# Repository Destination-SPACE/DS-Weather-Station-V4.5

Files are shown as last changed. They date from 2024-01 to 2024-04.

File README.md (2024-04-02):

<div align="center">
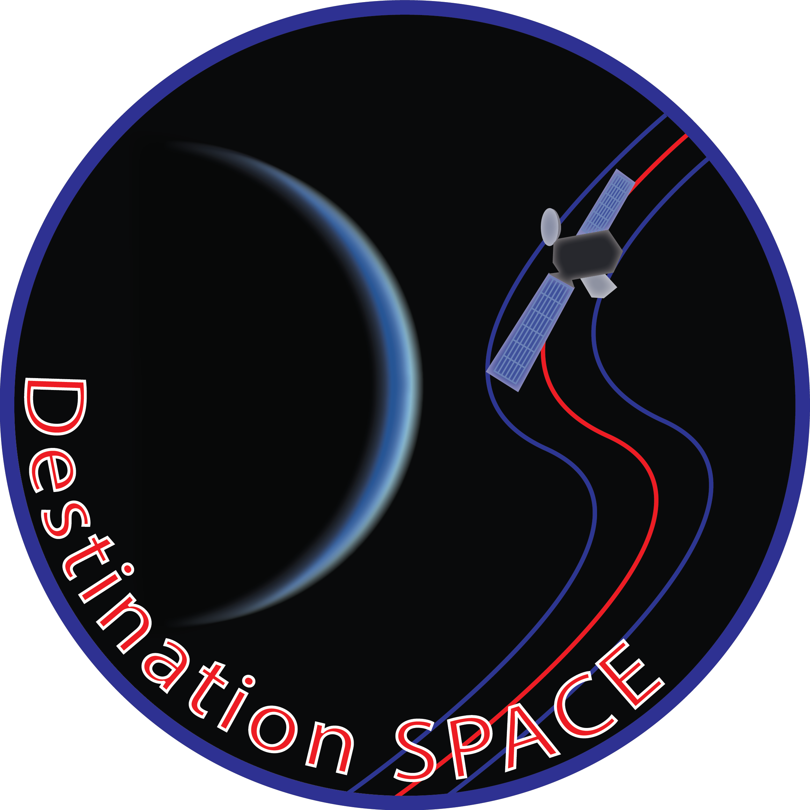
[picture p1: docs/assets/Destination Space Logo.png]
    
    <h1>Destination Weather Station v4.5.2</h1>
    <p>An Open Source Remote Sensing Platform for National Taiwan Normal University 🇹🇼</p>
</div>

## 🌟 About the Project
Destination Weather Station is the the latest version of remote sensing tools developed to teach students across Taiwan about climate science and remote sensing in partnership with National Taiwan Normal University.
## ⚙️ Hardware
All hardware files can be found [here](hardware/destinationWeatherStation_v4-5/)
## 💻 Software
All program files can be found [here](software)
## 🗂️ Documentation
Documentation for the weather station can be found [here](https://destination-space.gitlab.io/ds-weather-station-v4.5/)
## Licenses
Each of the above sections are individually licensed. Terms and conditions apply within their respective folders.

**Documentation - [Apache License 2.0](docs/LICENSE)** <br>
**Hardware - [CERN-OHL-P](hardware/destinationWeatherStation_v4-5//LICENSE)** <br>
**Software - [The MIT License](software/LICENSE)**

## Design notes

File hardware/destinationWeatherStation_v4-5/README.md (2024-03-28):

# Destination Weather Station v4.5 Hardware
KiCad files for Destination Weather Station v4.5

## KiCanvas
View schematic and PCB files with [KiCanvas](https://kicanvas.org/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)

## Directory
### [🧾 Bill of Materials](bom/bom.md)
### [📄 Datasheets](datasheets)
### [📐 Gerbers](gerber)
### [📰 Schematics](pdf)

Licensed under [CERN-OHL-P](LICENSE)

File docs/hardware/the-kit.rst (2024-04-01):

.. Copyright 2024 Destination SPACE Inc.
   Licensed under the Apache License, Version 2.0 (the "License");
   you may not use this file except in compliance with the License.
   You may obtain a copy of the License at

      http://www.apache.org/licenses/LICENSE-2.0

   Unless required by applicable law or agreed to in writing, software
   distributed under the License is distributed on an "AS IS" BASIS,
   WITHOUT WARRANTIES OR CONDITIONS OF ANY KIND, either express or implied.
   See the License for the specific language governing permissions and
   limitations under the License.

.. _the-kit:

What is in the Kit?
===================

.. Insert kit image here

Kit Contents
------------
- Destination Weather Station v4.5.2
- Seeeduino XIAO RP2040 microcontroller w/ headers
- 128x64px OLED display w/ headers
- SPDT power switch
- AAA battery case
- 8GB micro-SD card
- USB-A to USB-C cable
- USB microSD card adapter

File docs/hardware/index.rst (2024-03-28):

.. Copyright 2024 Destination SPACE Inc.
   Licensed under the Apache License, Version 2.0 (the "License");
   you may not use this file except in compliance with the License.
   You may obtain a copy of the License at

      http://www.apache.org/licenses/LICENSE-2.0

   Unless required by applicable law or agreed to in writing, software
   distributed under the License is distributed on an "AS IS" BASIS,
   WITHOUT WARRANTIES OR CONDITIONS OF ANY KIND, either express or implied.
   See the License for the specific language governing permissions and
   limitations under the License.

.. _hardware:

Overview of Hardware
====================

The Destination Weather Station was designed in `KiCad <https://www.kicad.org/>`_ and assembled by hand. the weather station includes several features that improve user experience. These are:

.. toctree::
   :maxdepth: 1

   power
   storage
   hid

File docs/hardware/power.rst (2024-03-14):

.. Copyright 2024 Destination SPACE Inc.
   Licensed under the Apache License, Version 2.0 (the "License");
   you may not use this file except in compliance with the License.
   You may obtain a copy of the License at

      http://www.apache.org/licenses/LICENSE-2.0

   Unless required by applicable law or agreed to in writing, software
   distributed under the License is distributed on an "AS IS" BASIS,
   WITHOUT WARRANTIES OR CONDITIONS OF ANY KIND, either express or implied.
   See the License for the specific language governing permissions and
   limitations under the License.

.. _power:

Power
=====

The power subsystem of the weather station was designed with reverse voltage protection in mind. Typically, if a battery is connected to a circuit backwards, it will not work, or worse, fry the entire system. This is why reverse current protection is often added to circuits to prevent such user error. This allows the user to not have to worry about the polarity of their LiPo battery. On the Destination Weather Station v4.5 we have taken this one step further, by not only having reverse voltage/polarity protection, but also correcting this polarity. This works using the same principal as an `AC rectifier <https://en.wikipedia.org/wiki/Rectifier>`_ circuit. This DC rectifier consists of two `N-Channel MOSFETs <https://en.wikipedia.org/wiki/NMOS_logic>`_ and two `P-Channel MOSFETs <https://en.wikipedia.org/wiki/PMOS_logic>`_. These MOSFETs combine to essentially create a rectifier circuit, which will only allow the correct polarity to pass through the FETs. A schematic of this circuit can be found below.

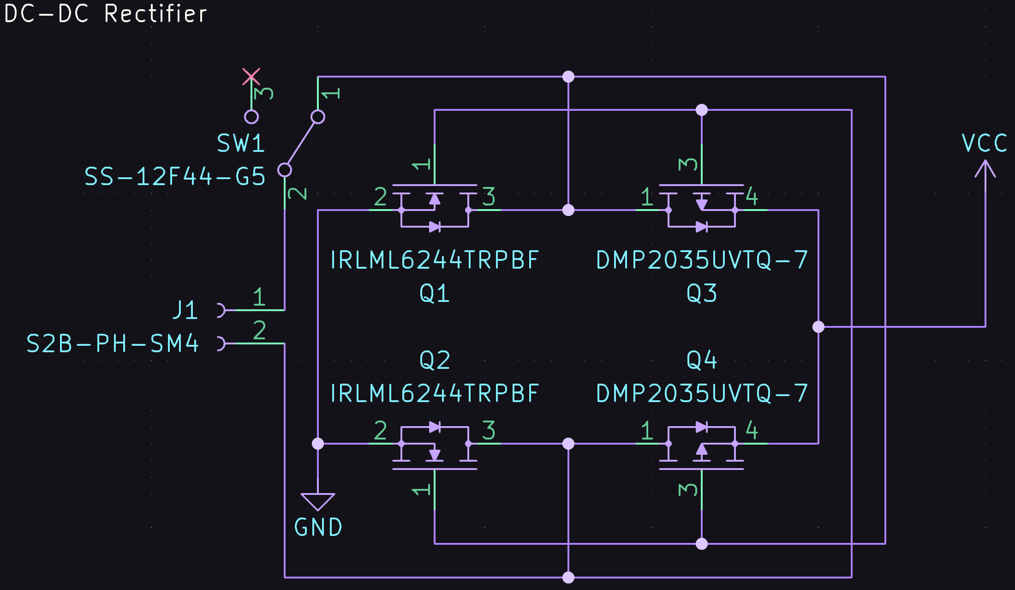
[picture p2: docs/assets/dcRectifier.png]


**Note:** There is no over-current protection, so make sure to not exceed 5V in.

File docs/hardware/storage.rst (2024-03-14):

.. Copyright 2024 Destination SPACE Inc.
   Licensed under the Apache License, Version 2.0 (the "License");
   you may not use this file except in compliance with the License.
   You may obtain a copy of the License at

      http://www.apache.org/licenses/LICENSE-2.0

   Unless required by applicable law or agreed to in writing, software
   distributed under the License is distributed on an "AS IS" BASIS,
   WITHOUT WARRANTIES OR CONDITIONS OF ANY KIND, either express or implied.
   See the License for the specific language governing permissions and
   limitations under the License.

.. _storage:

Storage
=======

The storage on the Destination Weather station is simply a microSD card slot to store recorded sensor data for further evalulation. There is also chip-detect functionality which allows the code to know if a card has been inserted or not.

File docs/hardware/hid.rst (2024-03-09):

.. Copyright 2024 Destination SPACE Inc.
   Licensed under the Apache License, Version 2.0 (the "License");
   you may not use this file except in compliance with the License.
   You may obtain a copy of the License at

      http://www.apache.org/licenses/LICENSE-2.0

   Unless required by applicable law or agreed to in writing, software
   distributed under the License is distributed on an "AS IS" BASIS,
   WITHOUT WARRANTIES OR CONDITIONS OF ANY KIND, either express or implied.
   See the License for the specific language governing permissions and
   limitations under the License.

.. _hid:

Human Interface Devices
=======================

On the Destination Weather Station there are 4 buttons, which are the primary way to interact with the device. These buttons are each labeled with arrows ↑, ↓, ←, →. These buttons are used to scroll through the menus and to switch between the different data displays.

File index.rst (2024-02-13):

.. Copyright 2024 Destination SPACE Inc.
   Licensed under the Apache License, Version 2.0 (the "License");
   you may not use this file except in compliance with the License.
   You may obtain a copy of the License at

      http://www.apache.org/licenses/LICENSE-2.0

   Unless required by applicable law or agreed to in writing, software
   distributed under the License is distributed on an "AS IS" BASIS,
   WITHOUT WARRANTIES OR CONDITIONS OF ANY KIND, either express or implied.
   See the License for the specific language governing permissions and
   limitations under the License.

Destination Weather Station v4.5
================================

An Open Source Remote Sensing Platform for National Taiwan Normal University

Contents
--------

.. toctree::
   :maxdepth: 1

   about-the-project

.. toctree::
   :caption: Getting Started
   :maxdepth: 1

   hardware/the-kit
   hardware/assembly
   tutorials/index

.. toctree::
   :caption: Configuration
   :maxdepth: 1

   software/install-arduino-ide
   software/weather-station-configuration

.. toctree::
   :caption: Experiments

.. toctree::
   :caption: Sensors
   :maxdepth: 1

   sensors/index
   sensors/calibration
   sensors/bme280
   sensors/ens160
   sensors/scd40
   sensors/veml7700
   sensors/ltr390

.. toctree::
   :caption: Hardware
   :maxdepth: 1

   hardware/index
   faq/troubleshooting
   hardware/power
   hardware/storage
   hardware/hid
   hardware/pcb/index
   hardware/pcb/manufacturing

.. toctree::
   :caption: Software
   :maxdepth: 1

   software/index
   software/blink
   software/basics
   software/i2c-scanner
   software/sensor-test
   software/demo

.. toctree::
   :caption: Miscellaneous
   :maxdepth: 1

   FAQ <faq/index>

.. * :ref:`genindex`
.. * :ref:`modindex`
.. * :ref:`search`

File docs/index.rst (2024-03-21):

.. Copyright 2024 Destination SPACE Inc.
   Licensed under the Apache License, Version 2.0 (the "License");
   you may not use this file except in compliance with the License.
   You may obtain a copy of the License at

      http://www.apache.org/licenses/LICENSE-2.0

   Unless required by applicable law or agreed to in writing, software
   distributed under the License is distributed on an "AS IS" BASIS,
   WITHOUT WARRANTIES OR CONDITIONS OF ANY KIND, either express or implied.
   See the License for the specific language governing permissions and
   limitations under the License.

Destination Weather Station v4.5
================================

An Open Source Remote Sensing Platform for National Taiwan Normal University

Contents
--------



.. toctree::
   :caption: Getting Started
   :maxdepth: 2

   hardware/the-kit
   hardware/assembly

.. toctree::
   :caption: Configuration
   :maxdepth: 2

   software/install-arduino-ide

.. toctree::
   :caption: Sensors
   :maxdepth: 2

   sensors/index
   sensors/bme280
   sensors/ens160
   sensors/ltr390
   sensors/scd40
   sensors/veml7700

.. toctree::
   :caption: Hardware
   :maxdepth: 2

   hardware/index
   faq/troubleshooting
   hardware/power
   hardware/storage
   hardware/hid

.. toctree::
   :caption: Software
   :maxdepth: 2

   software/index
   software/blink
   software/sensor-test
   software/demo
   software/full-code

.. toctree::
   :caption: Activities
   :maxdepth: 2

   activities/index
   activities/tempurature
   activities/humidity
   activities/CO2
   activities/VOCs
   activities/ALS
   activities/UVA

.. toctree::
   :caption: Miscellaneous
   :maxdepth: 2

   FAQ <faq/index>

.. * :ref:`genindex`
.. * :ref:`modindex`
.. * :ref:`search`

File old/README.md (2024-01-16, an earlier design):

# Destination Weather Station v4.5 Documentation
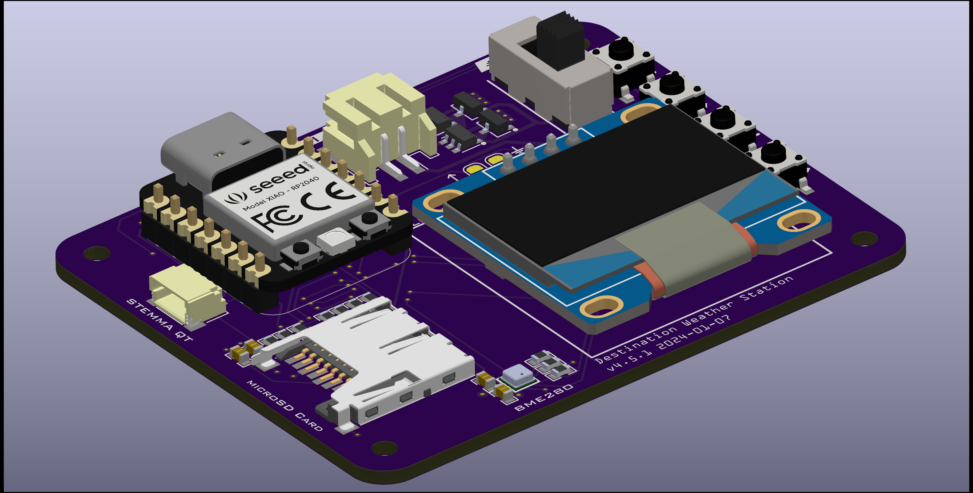
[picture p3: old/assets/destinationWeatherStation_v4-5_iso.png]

## Directory
[//]: # (Directory Links)
<div>
<h3>
<details>
  <summary><a href="#-getting-started">🚀 Getting Started</a></summary>
  <ul>
    <li><a href="#-whats-included">📝 What's Included</a></li>
    <details>
        <summary><a href=#-getting-started>🔧 Soldering</a></summary>
        <ul>
        <li><a href="#step-1">Step 1</a></li>
        <li><a href="#step-2">Step 2</a></li>
        <li><a href="#step-3">Step 3</a></li>
        <li><a href="#step-4">Step 4</a></li>
        <li><a href="#step-5">Step 5</a></li>
        </ul>
    </details>
    <li><a href="#final-assembly">Final Assembly</a></li>
  </ul>
</details>
</h3>

<h3>
<details>
  <summary><a href="uploading-code.md">💻 Uploading Code</a></summary>
  <ul>
    <li><a href="uploading-code.md#💾-downloading-arduino-ide">💾 Downloading Arduino IDE</a></li>
    <details>
        <summary><a href="uploading-code.md#💻-configuring-arduino-ide">💻 Configuring Arduino IDE</a></summary>
        <ul>
        <li><a href="uploading-code.md#📥-installing-board-manager">📥 Installing Board Manager</a></li>
        <li><a href="uploading-code.md#📥-installing-code-libraries">📥 Installing Code Libraries</a></li>
        </ul>
    </details>
    <li><a href="uploading-code.md#👾-example-programs">👾 Example Programs</a></li>
  </ul>
</details>
</h3>

<h3>
<details>
  <summary><a href="collecting-data.md">🗃️ Collecting Data</a></summary>
  <ul>
    <li><a href="">Domain 1</a></li>
    <details>
        <summary><a href=>Sub-Domain List 1</a></summary>
        <ul>
        <li><a href="">Sub-Domain 1</a></li>
        <li><a href="">Sub-Domain 2</a></li>
        <li><a href="">Sub-Domain 3</a></li>
        <li><a href="">Sub-Domain 4</a></li>
        <li><a href="">Sub-Domain 5</a></li>
        </ul>
    </details>
    <li><a href="">Domain 2</a></li>
  </ul>
</details>
</h3>

<h3>
<details>
  <summary><a href="collecting-data.md">🧪 Experiments</a></summary>
  <ul>
    <li><a href="">Domain 1</a></li>
    <details>
        <summary><a href=>Sub-Domain List 1</a></summary>
        <ul>
        <li><a href="">Sub-Domain 1</a></li>
        <li><a href="">Sub-Domain 2</a></li>
        <li><a href="">Sub-Domain 3</a></li>
        <li><a href="">Sub-Domain 4</a></li>
        <li><a href="">Sub-Domain 5</a></li>
        </ul>
    </details>
    <li><a href="">Domain 2</a></li>
  </ul>
</details>
</h3>
</div>

## 🚀 Getting Started

### 📝 What's Included
- 1x Destination Weather Station v4.5
- 1x Seeeduino XIAO RP2040 microcontroller with headers
- 1x 128x64px OLED display with headers
- 1x SPDT slide switch
- 1x 4.5V AAA battery case
- 3x AAA batteries
- 1x USB A to USB C cable
- 1x 8GB microSD card
- 1x microSD to USB A adapter

### 🔧 Soldering

#### Step 1:
- Take 2 1x7 male header pins and insert the long side of the pins into the board
- Carefully flip the board upside-down, without letting the headers fall out
- Place the tip of the soldering iron at the corner between the 1st pin and the gold pad, allowing it to heat up the board for 2-3 seconds
- Feed solder onto the pad with your other hand. The solder should melt and flow around the pad and pin.
- Remove the soldering iron after 2-3 more seconds
- Repeat with the 7th pin, then the other pins in the middle
- Repeat with the other 1x7 header

#### Step 2:
- Following the same steps above, solder the 1x4 header to the board

#### Step 3:
- Place the Seeeduino XIAO RP2040 on the 1x7 headers, with the USB C port and buttons facing up
- Following the same soldering techniques, solder all 14 pins on the XIAO

#### Step 4:
- Place the OLED display on the 1x4 header with the screen facing up
- Solder the first pin using the same technique used for the other pins
- Before soldering the other pins, hold the screen with one hand, and heat up the soldered pad
- Adjust the screen so it is flat with the weather station board
- Solder the 4th pin, then the 2 middle pins

#### Step 5:
- Insert the SPDT switch into the weather station board
- Carefully flip the board upside-down, without letting the button fall out
- Using the same technique as before, solder the 2 outside pins of the switch, then solder the 3 middle pins

### Final Assembly
- Insert the AAA batteries into the battery case
- Insert the microSD card into the weather station
- Write your name on the back of the weather station in the white box provided

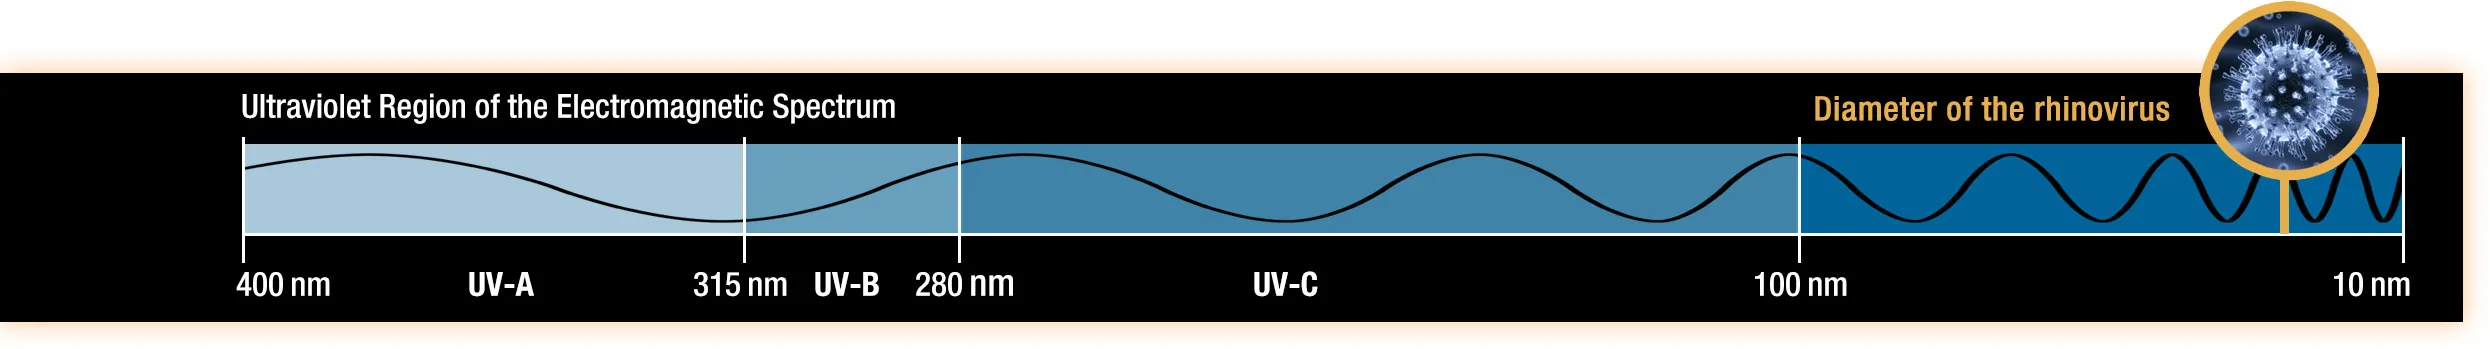
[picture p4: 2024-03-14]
docs/assets/ultravioletSpectrum.webp

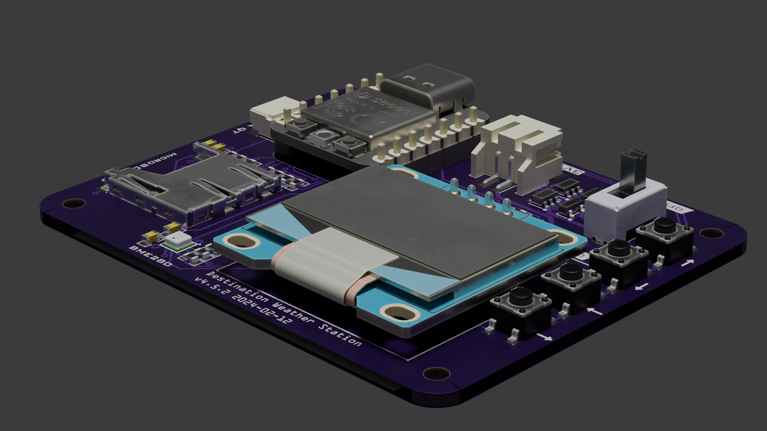
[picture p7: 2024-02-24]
hardware/destinationWeatherStation_v4-5/blender/firstRender.png

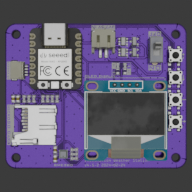
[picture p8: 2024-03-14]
hardware/destinationWeatherStation_v4-5/blender/thumbnail2.png

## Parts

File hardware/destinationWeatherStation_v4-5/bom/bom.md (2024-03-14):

# Bill of Materials
*Note: Some parts may be replaced with suitable alternatives

| Item | Qty | Reference | Value | Datasheet | Manufacturer | Manufacturer Part Number | Package |
|-----:|----:|:---:|:-----:|:---|:---|:---|---:|
| 1 | 1 | C1 | 10uF | [AVX-CX5R-KGM](../datasheets/AVX-CX5R-KGM-MLCC.pdf) | KYOCERA AVX | KGM15CR51A106MT | 0603 |
| 2 | 3 | C2, C3, C4 | 0.1uF | [AVX-CX5R-KGM](../datasheets/AVX-CX5R-KGM-MLCC.pdf) | KYOCERA AVX | KGM15AR51H104KT | 0603 | 
| 3 | 10 | R1, R2, R3, R4, R5, R6, R7, R8, R9, R10 | 10K | [D/CRCW e3](../datasheets/Vishay-Dale-DCRCWe3.pdf) | Vishay Dale | CRCW060310K0JNEB | 0603 |
| 3 | 2 | R11, R12 | 0R | [D/CRCW e3](../datasheets/Vishay-Dale-DCRCWe3.pdf) | Vishay Dale | CRCW06030000Z0EA | 0603 |
| 4 | 2 | Q1, Q2 | IRLML6244TRPBF | [IRLML6244TRPBF](../datasheets//Infineon-IRLML6244.pdf) | Infineon Technologies | IRLML6244TRPBF | SOT-23 |
| 5 | 2 | Q3, Q4 | DMP2035UVTQ | [DMP2035UVTQ](../datasheets/Diodes-Incorporated-DMP2035UVTQ.pdf) | Diodes Incorporated | DMP2035UVTQ-7 | TSOT26 |
| 6 | 1 | U1 | XIAO RP2040 | [XIAO RP2040](https://wiki.seeedstudio.com/XIAO-RP2040/) | Seeed Studio | XIAO RP2040 | N/A |
| 7 | 1 | U2 | BME280 | [BME280](../datasheets/BST-BME280.pdf) | Bosch Sensortec | BME280 | 2.5x2.5mm LGA |
| 8 | 1 | U3 | OLED | [HS96L03W2C03](../datasheets/HS-HS96L03W2C03.pdf) | SHENZHEN HANSHENG INDUSTRAIL CO. | HS96L03W2C03 | N/A |
| 9 | 1 | SW1 | SS-12F44-G5 | [SS-12F44-G5](../datasheets/SS-12D07-VG_GA_PA.pdf) | C&K | SS-12D07-VG 4 NS GA PA | N/A |
| 10 | 4 | SW2, SW3, SW4, SW5 | PTS647SM38SMTR2LFS | [PTS647SM38SMTR2LFS](../datasheets/C&K-PTS647.pdf) | C&K | PTS 647 SM38 SMTR2 LFS | N/A |
| 11 | 1 | J1 | S2B-PH-SM4 | [JST-PH](../datasheets/JST-PH-Connectors.pdf) | JST Sales America Inc. | S2B-PH-SM4-TB(LF)(SN) | N/A |
| 12 | 1 | J2 | MEM2061 | [MEM2061](../datasheets//GCT-MEM2061.pdf) | GCT | MEM2061-01-188-00-A | N/A |
| 13 | 1 | J3 | SM04B-SRSS | [JST-SH](../datasheets/JST-SH-Connectors.pdf) | JST Sales America Inc. | SM04B-SRSS-TB | N/A |

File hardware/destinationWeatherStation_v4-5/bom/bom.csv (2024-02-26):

Item | Qty | Reference(s) | Value | Manufacturer | mpn | populate
1 | 1 | C1 | 10uF | KYOCERA AVX | KGM15CR51A106MT | 1
2 | 3 | C2, C3, C4 | 100nF | KYOCERA AVX | KGM15AR51H104KT | 1
3 | 1 | J1 | S2B-PH-SM4 | JST Sales America Inc. | S2B-PH-SM4-TB(LF)(SN) | 1
4 | 1 | J2 | MEM2061 | GCT | MEM2061-01-188-00-A | 1
5 | 1 | J3 | STEMMA_QT | JST Sales America Inc. | SM04B-SRSS-TB | 1
6 | 2 | Q1, Q2 | IRLML6244TRPBF | Infineon Technologies | IRLML6244TRPBF | 1
7 | 1 | Q3 | DMP2035UVTQ-7 | Diodes Incorporated | DMP2035UVTQ-7 | 1
8 | 1 | Q4 | DMP2035UVTQ-7 | Diodes Incorporated | DMP2035UVTQ-7 | 1
9 | 10 | R1, R2, R3, R4, R5, R6, R7, R8, R9, R10 | 10K | Vishay Dale | CRCW060310K0JNEB | 1
10 | 2 | R11, R12 | 0R | Vishay Dale | CRCW06030000Z0EA | 1
11 | 1 | SW1 | SS-12F44-G5 | C&K | SS-12D07-VG 4 NS GA PA | 0
12 | 4 | SW2, SW3, SW4, SW5 | PTS647SM38SMTR2LFS | C&K | PTS 647 SM38 SMTR2 LFS | 1
13 | 1 | U1 | XIAO RP2040 | Seeed Studio | XIAO RP2040 | 0
14 | 1 | U2 | BME280 | Bosch Sensortec | BME280 | 1
15 | 1 | U3 | HS96L03W2C03 | SHENZHEN HANSHENG INDUSTRAIL CO. | HS96L03W2C03 | 0

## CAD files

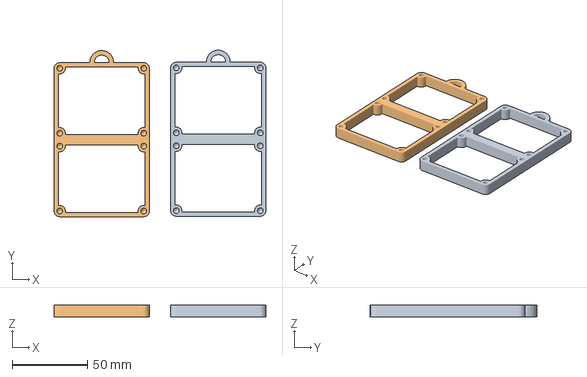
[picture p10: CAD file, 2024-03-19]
hardware/balloonMount/balloonMount_x2.3mf
141.0 x 110.8 x 8.00 mm
balloonMount_x2.stl x 2

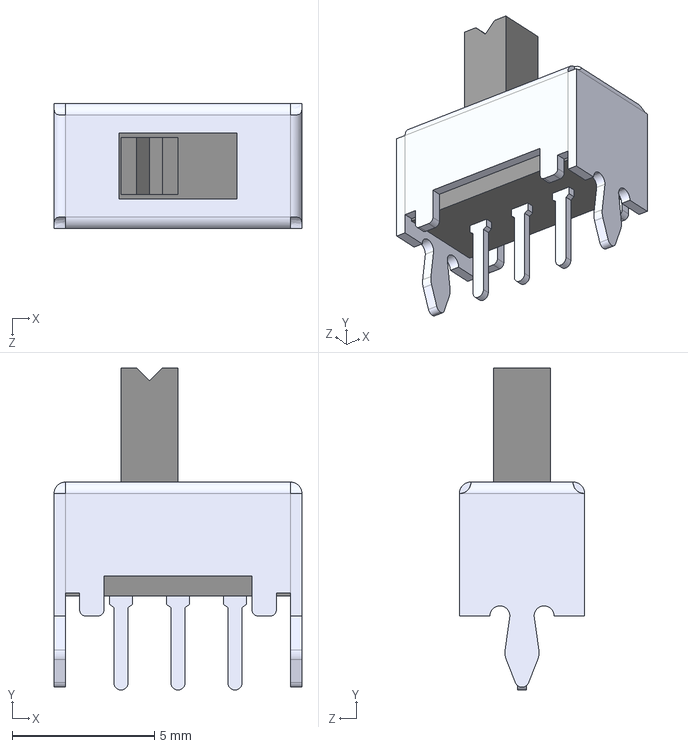
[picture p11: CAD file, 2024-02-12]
hardware/destinationWeatherStation_v4-5/3d_models/SS12D07VG4.STEP
8.70 x 11.3 x 4.40 mm

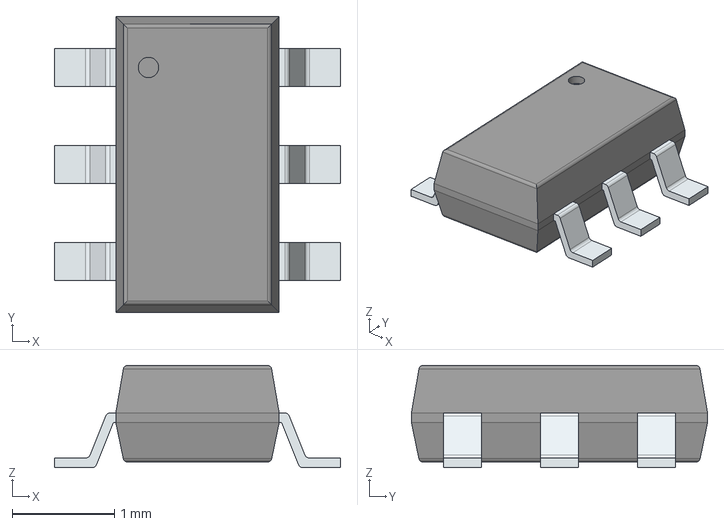
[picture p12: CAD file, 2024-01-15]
hardware/destinationWeatherStation_v4-5/3d_models/DMP2035UVTQ-7.stp
2.80 x 2.90 x 1.00 mm
PinsArrayLR

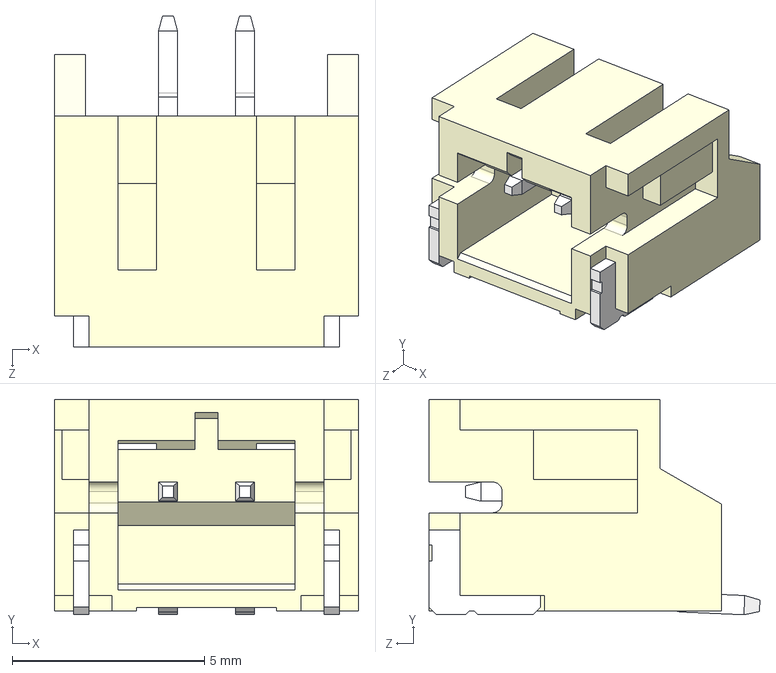
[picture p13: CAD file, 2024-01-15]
hardware/destinationWeatherStation_v4-5/3d_models/S2B-PH-SM4-TB(LF)(SN).STEP
7.90 x 5.60 x 8.60 mm

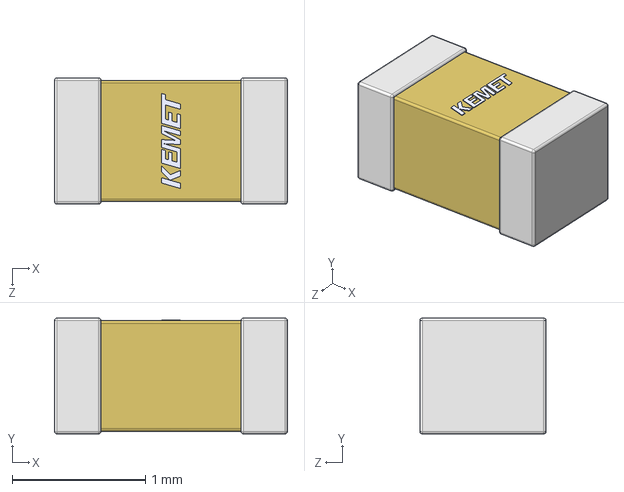
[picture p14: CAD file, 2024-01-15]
hardware/destinationWeatherStation_v4-5/3d_models/C0603C104K5RACTU.stp
1.75 x 0.87 x 0.95 mm

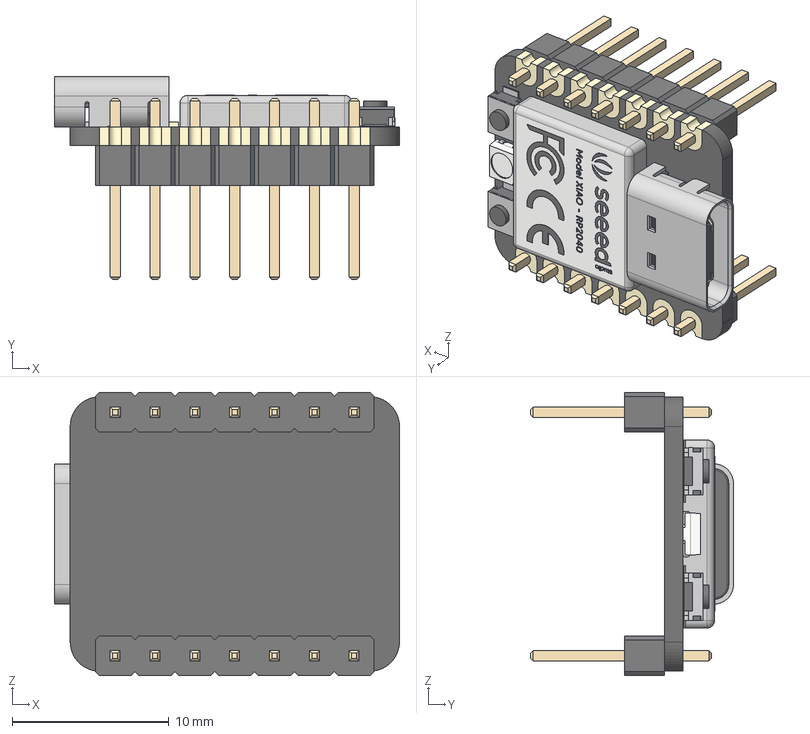
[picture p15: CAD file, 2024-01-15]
hardware/destinationWeatherStation_v4-5/3d_models/xiaoRP2040_with_pins.stp
22.0 x 12.9 x 18.1 mm
type-c v2
smd_button v3
DOUT
DIN
VSS
VDD
smd_button v3(Mirror)
PinHeader_1x07_P254mm_Vertical x 2

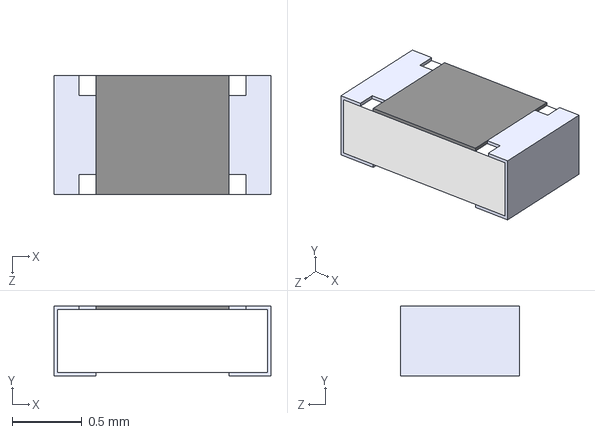
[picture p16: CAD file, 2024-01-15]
hardware/destinationWeatherStation_v4-5/3d_models/CRCW0603.STEP
1.55 x 0.5 x 0.85 mm

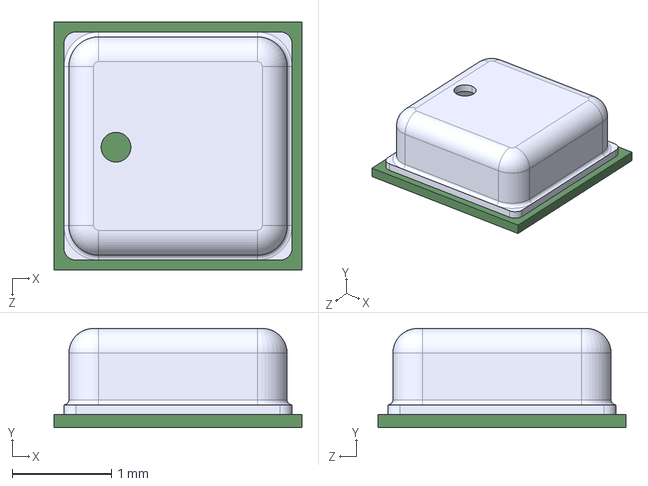
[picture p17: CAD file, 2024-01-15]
hardware/destinationWeatherStation_v4-5/3d_models/BME280.STEP
2.50 x 1.00 x 2.50 mm

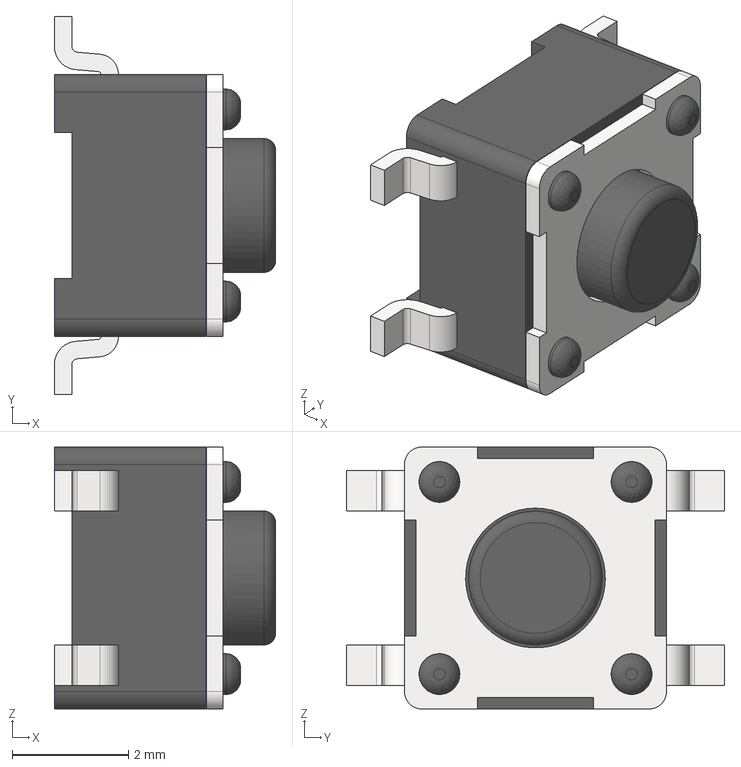
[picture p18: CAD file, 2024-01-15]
hardware/destinationWeatherStation_v4-5/3d_models/PTS647SM38SMTR2LFS.stp
3.80 x 6.50 x 4.50 mm

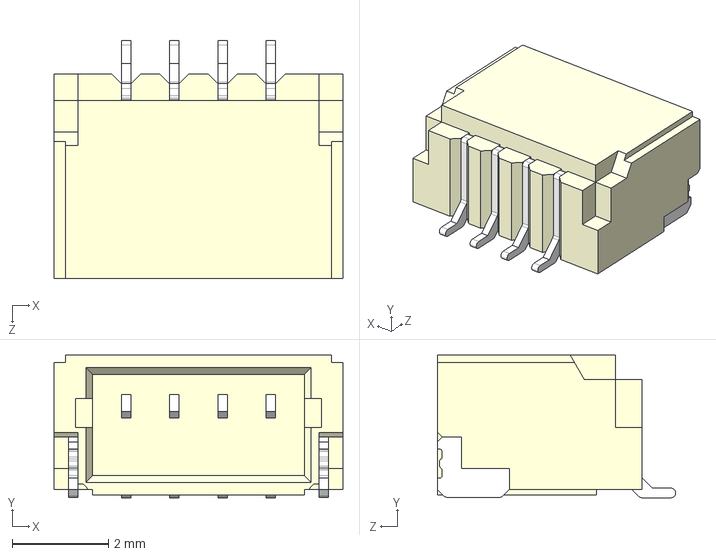
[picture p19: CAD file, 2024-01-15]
hardware/destinationWeatherStation_v4-5/3d_models/SM04B-SRSS-TB(LF)(SN).STEP
6.00 x 2.96 x 4.95 mm

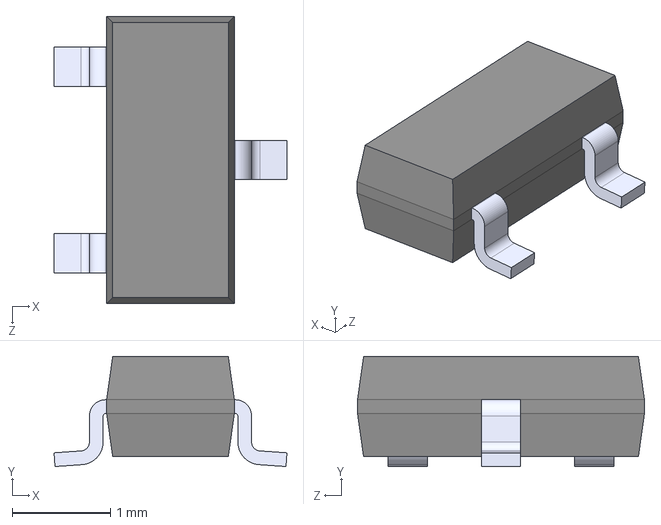
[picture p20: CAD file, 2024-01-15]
hardware/destinationWeatherStation_v4-5/3d_models/IRLML6244TRPBF.STEP
2.37 x 1.12 x 2.92 mm

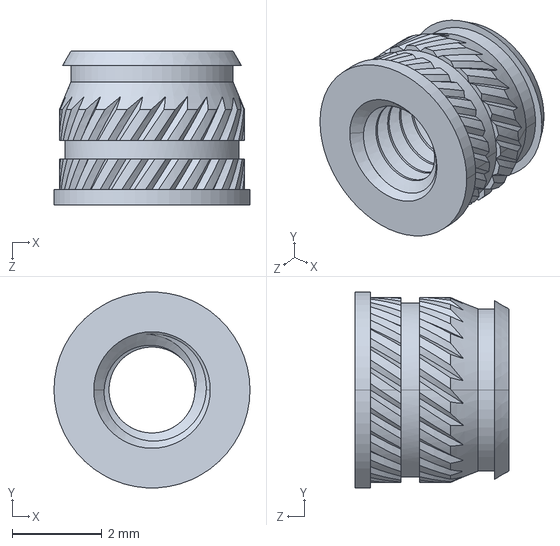
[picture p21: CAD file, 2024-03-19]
hardware/balloonMount/94180A321_Tapered Heat-Set Inserts for Plastic.STEP
4.37 x 4.36 x 3.43 mm

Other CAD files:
hardware/balloonMount/94180A321_Tapered Heat-Set Inserts for Plastic/94180A321_Tapered Heat-Set Inserts for Plastic.ipt
hardware/balloonMount/OldVersions/balloonMount.0002.iam
hardware/balloonMount/balloonMount.iam
hardware/balloonMount/balloonMount_x2.ipt
hardware/balloonMount/balloonMount_x2.stl
hardware/balloonMount/destination-automation-v4.5-test-jig/destination-automation-v4.5-test-jig.ipt
hardware/balloonMount/destinationAutomation_r4/OldVersions/destinationAutomation_r4.0001.ipt
hardware/balloonMount/destinationAutomation_r4/destinationAutomation_r4.ipt
hardware/balloonMount/destinationWeatherStation_v4-5/ASSEMBLY.ipt
hardware/balloonMount/destinationWeatherStation_v4-5/Assembly1.ipt
hardware/balloonMount/destinationWeatherStation_v4-5/BME280.iam
hardware/balloonMount/destinationWeatherStation_v4-5/BME280.ipt
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

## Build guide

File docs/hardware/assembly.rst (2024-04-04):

.. Copyright 2024 Destination SPACE Inc.
   Licensed under the Apache License, Version 2.0 (the "License");
   you may not use this file except in compliance with the License.
   You may obtain a copy of the License at

      http://www.apache.org/licenses/LICENSE-2.0

   Unless required by applicable law or agreed to in writing, software
   distributed under the License is distributed on an "AS IS" BASIS,
   WITHOUT WARRANTIES OR CONDITIONS OF ANY KIND, either express or implied.
   See the License for the specific language governing permissions and
   limitations under the License.

.. _assembly:

Destination Weather Station v4.5 Assembly
=========================================

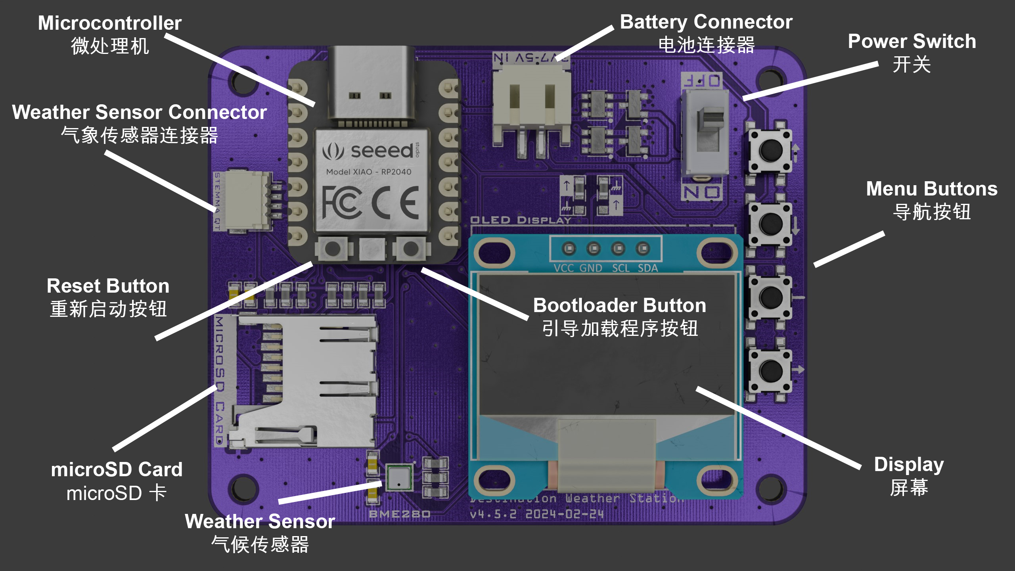
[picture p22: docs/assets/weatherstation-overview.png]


The Destination Weather Station v4.5 is preassembled with the majority of the circuit components.

Before using the weather station, you will need to :ref:`solder<soldering>` the :ref:`XIAO RP2040 microcontroller<xiao-RP2040>`, :ref:`OLED display<oled-display>`, and :ref:`power switch<switch>`. Follow the instructions below to solder your weather station. You can then :ref:`connect the batteries<batteries>` and insert the microSD card.

Soldering
---------

.. _soldering:

To solder the weather station, follow the instructions below. Tools required to complete these steps are:

* Soldering iron
* Solder wire

Power Switch
~~~~~~~~~~~~

.. _switch:

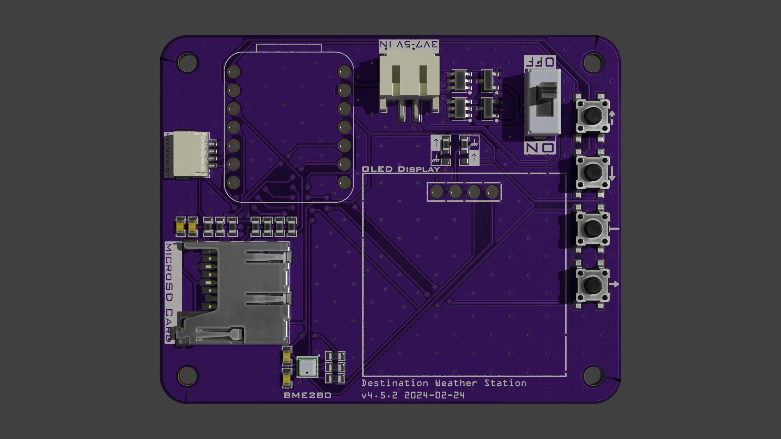
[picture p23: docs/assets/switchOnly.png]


To solder the power switch to the weather station, insert it into the front side of the board. Flip the board over and solder the pins, starting with the two outer ones.

XIAO RP2040
~~~~~~~~~~~

.. _xiao-RP2040:

To solder the XIAO RP2040 to the weather station, begin by inserting the long side of the 1x7 header pins into the weather station board as shown below.

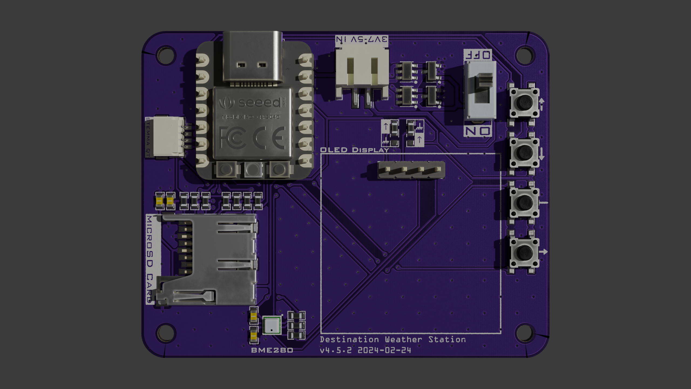
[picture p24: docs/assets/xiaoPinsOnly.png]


Next, flip the weather station over and solder all 14 pins to the weather station.

Finally, flip the weather station back over and solder the XIAO to the short side of the header pins. After you are done, it should look like the image below.

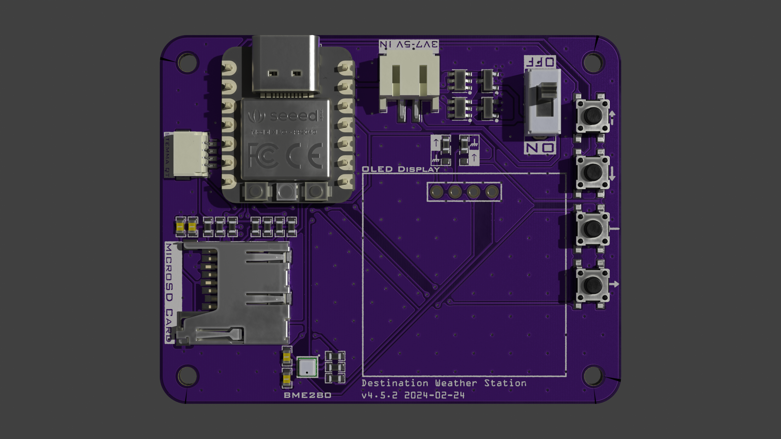
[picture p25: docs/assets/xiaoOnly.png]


OLED Display
~~~~~~~~~~~~

.. _oled-display:

To solder the OLED display to the weather station, you will follow similar procedures to the steps above to solder the XIAO.

Begin by inserting the long side of the 1x4 header into the weather station board as shown below.

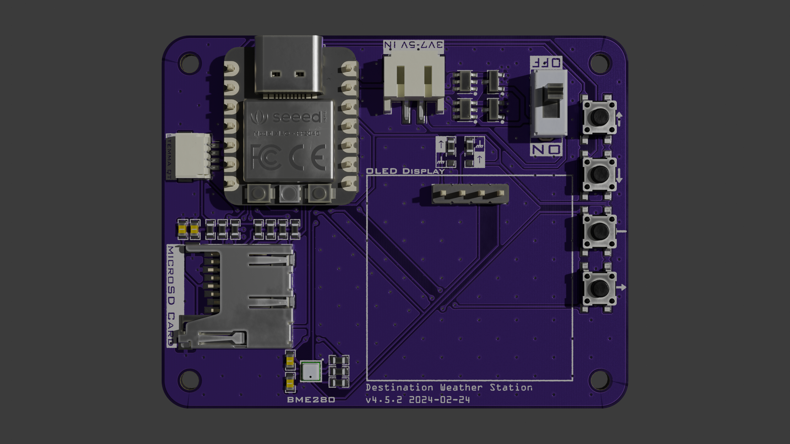
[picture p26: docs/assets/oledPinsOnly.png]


Next, flip the board over and solder the pins to the back.

Similarly, flip the board back over and solder the display to the front.



Final Assembly
--------------


Batteries
~~~~~~~~~

.. _batteries:

Insert three (3) AAA batteries into the battery pack. Connect the JST-PH connector to the matching connector on the weather station.

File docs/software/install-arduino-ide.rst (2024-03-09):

.. Copyright 2024 Destination SPACE Inc.
   Licensed under the Apache License, Version 2.0 (the "License");
   you may not use this file except in compliance with the License.
   You may obtain a copy of the License at

      http://www.apache.org/licenses/LICENSE-2.0

   Unless required by applicable law or agreed to in writing, software
   distributed under the License is distributed on an "AS IS" BASIS,
   WITHOUT WARRANTIES OR CONDITIONS OF ANY KIND, either express or implied.
   See the License for the specific language governing permissions and
   limitations under the License.

.. _install-arduino-ide:

Installing Arduino IDE
======================

To program the Destination Weather Station, you will need to download and install Arduino IDE.

Download
~~~~~~~~

To begin, navigate to https://www.arduino.cc/en/software.

Click ``Windows Win 10 and newer, 64 bits`` under the most recent version of IDE. This may be different than the screenshot below

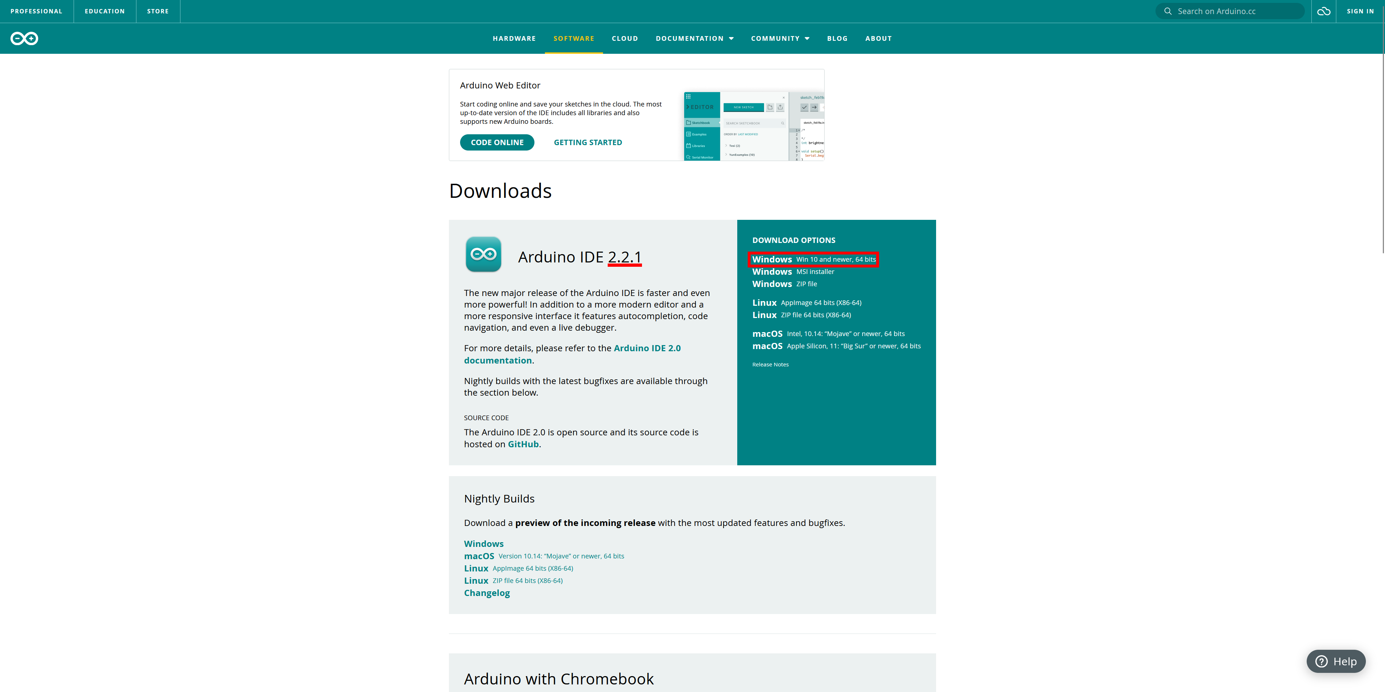
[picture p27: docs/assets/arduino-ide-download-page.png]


When the page loads, click next

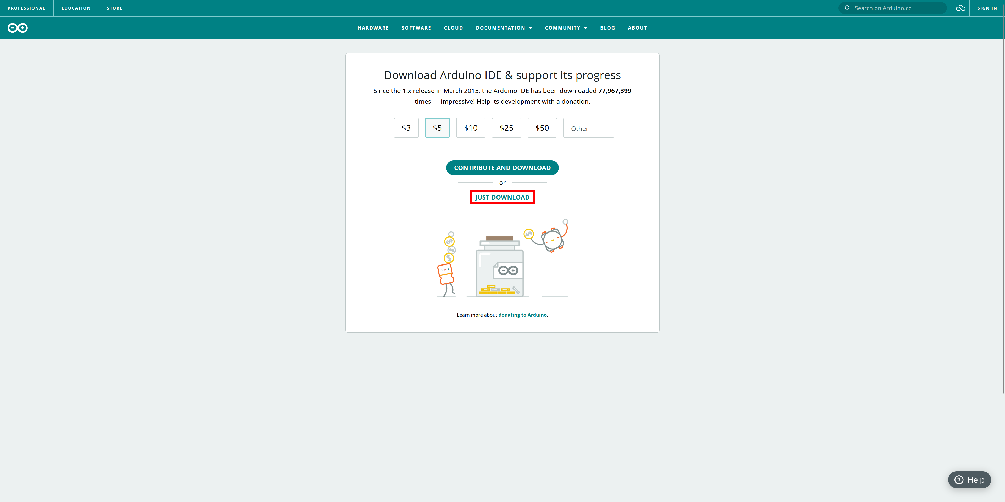
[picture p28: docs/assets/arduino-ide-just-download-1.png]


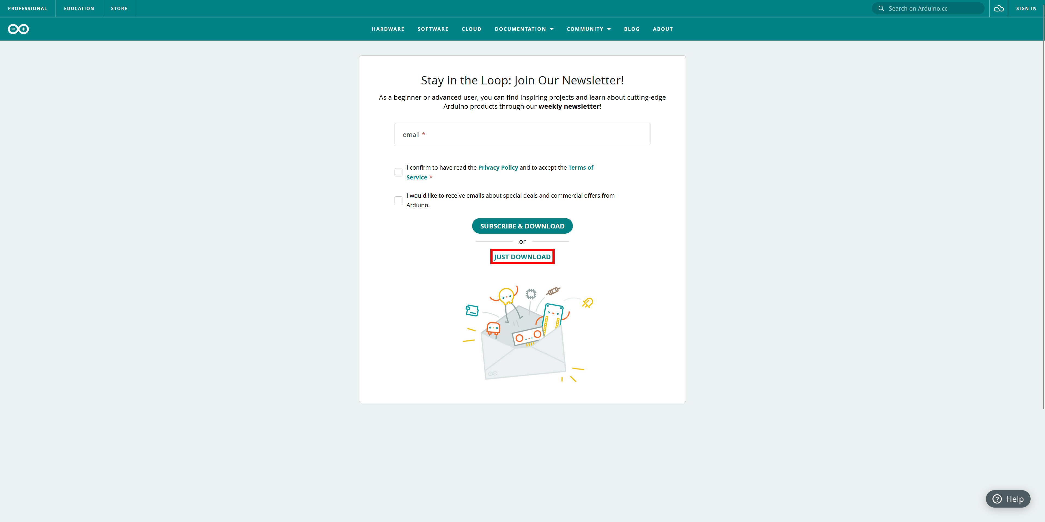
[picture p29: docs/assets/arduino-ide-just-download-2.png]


Installation
~~~~~~~~~~~~

To install Arduino IDE, navigate to where you saved your ``arduino-ide_2.x.x_Windows_64bit.exe`` file and follow the instructions in the install.

Software Configuration
======================

Board Manager
~~~~~~~~~~~~~

To properly configure IDE, the board manager for the XIAO RP2040 needs to be installed.

In Arduino IDE, navigate to **File > Preferences**. In the window, enter ``https://github.com/earlephilhower/arduino-pico/releases/download/global/package_rp2040_index.json`` into the **Additional boards manager URLs:** text box.

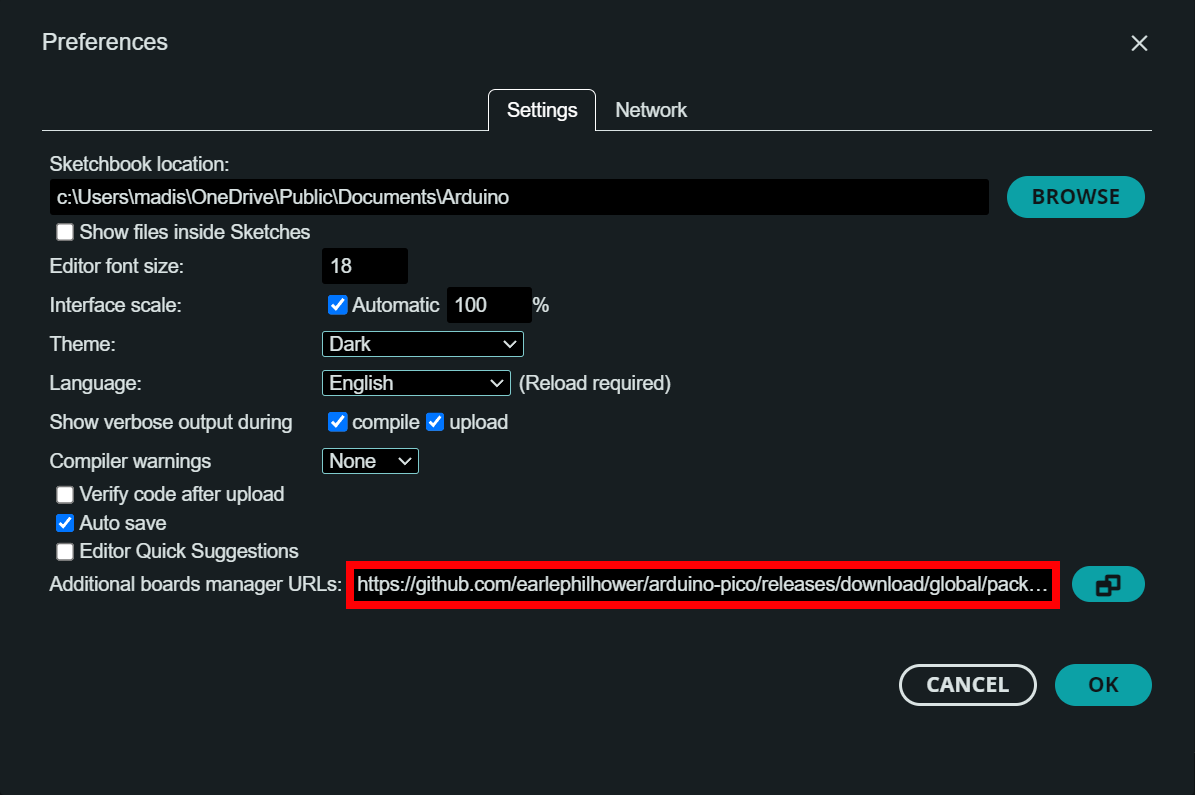
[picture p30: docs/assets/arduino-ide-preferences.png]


Click **OK**

Next, navigate to **Tools > Board: > Boards Manager...**. Search for ``Raspberry Pi Pico/RP2040`` and click **INSTALL** on the option published by Earle F. Philhower, III.

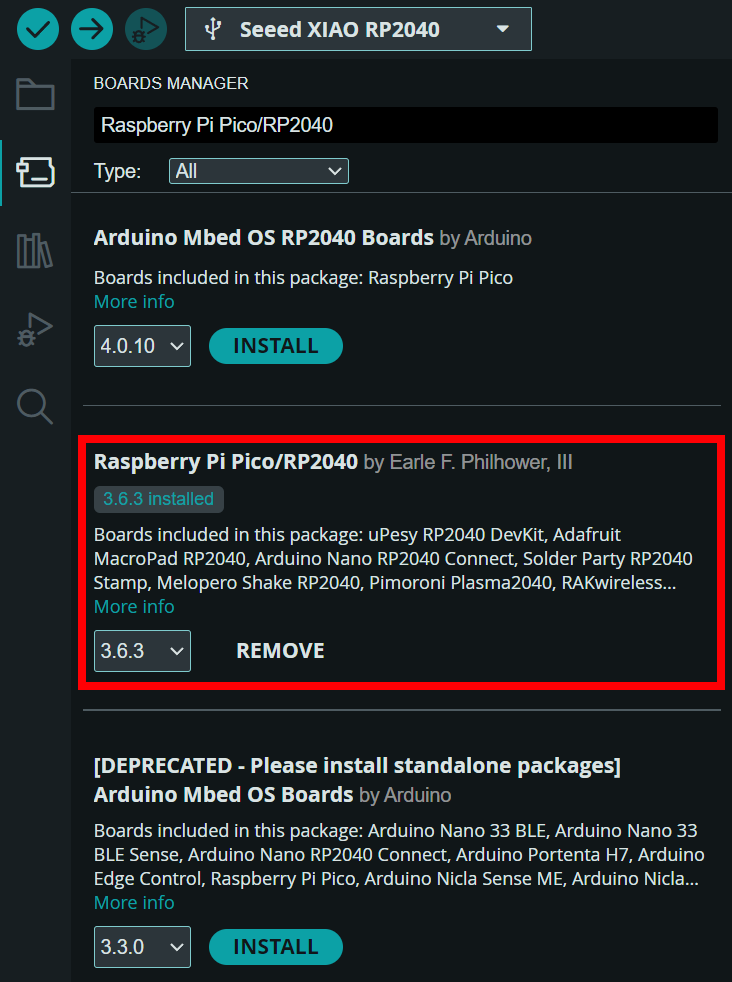
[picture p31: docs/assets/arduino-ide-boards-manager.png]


Code Libraries
~~~~~~~~~~~~~~

Several libraries are needed  to upload code to the weather station.

To install these libraries, navigate to **Tools > Manage Libraries...**

In the search box enter the following library names and install each including any required dependancies.

* ``Adafruit BME280 Library``
* ``Adafruit LTR390 Library``
* ``Adafruit SSD1306``
* ``Adafruit VEML7700 Library``
* ``ENS160 - Adafruit Fork``
* ``Sensirion I2C SCD4x``

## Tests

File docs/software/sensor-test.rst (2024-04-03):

.. Copyright 2024 Destination SPACE Inc.
   Licensed under the Apache License, Version 2.0 (the "License");
   you may not use this file except in compliance with the License.
   You may obtain a copy of the License at

      http://www.apache.org/licenses/LICENSE-2.0

   Unless required by applicable law or agreed to in writing, software
   distributed under the License is distributed on an "AS IS" BASIS,
   WITHOUT WARRANTIES OR CONDITIONS OF ANY KIND, either express or implied.
   See the License for the specific language governing permissions and
   limitations under the License.

.. _sensor-test:

Sensor Test Sketch
==================

The `Sensor Test <https://gitlab.com/Destination-SPACE/ds-weather-station-v4.5/-/blob/main/software/Sensor_Test/Sensor_Test.ino>`_ sketch is used to make sure the sensors on the weather station are working correctly. Use this sketch as the first program to upload after the `Blink <https://gitlab.com/Destination-SPACE/ds-weather-station-v4.5/-/blob/main/software/Blink/Blink.ino>`_ sketch.

Libraries
---------

For the Sensor Test sketch, many more libraries are required. These can be split into two categories; System libraries and sensor libraries. In this example only one system library is required, which is the `Wire Library <https://docs.arduino.cc/learn/communication/wire/#wire-library>`_. This is a default Arduino library and is used to communicate with sensors on the Inter-Integrated Circuit (I2C) protocol. More details about the protocol can be found `here <https://docs.arduino.cc/learn/communication/wire/>`_.

The libraries required to use all of the sensors on your weather stations and for the classroom expansion sensors have been pre-installed. A list of the libraries are below.

.. code-block:: cpp
   
   //Import system libraries
   #include <Wire.h>

   //Import sensor libraries
   #include <Adafruit_BME280.h>
   #include <Adafruit_LTR390.h>
   #include <Adafruit_Sensor.h>
   #include <Adafruit_VEML7700.h>
   #include <ScioSense_ENS160.h>
   #include <SensirionI2CScd4x.h>

Hardware Definitions
--------------------
Only one hardware definition is required for this example. This defines mean sea-level pressure, which is used to calculate an approximate value for altitude using temperature and pressure. By default, this value is set to 1013.25 hPa. You are welcome to change this value to the current sea-level pressure in your region. Click `here <>`_ to find out more about calculating barometric altitude.

.. code-block:: cpp
   
   #define SEALEVELPRESSURE_HPA (1013.25)

Define Sensor Functions
-----------------------

Several sensor functions need to be defined to get the sensors to work. This ensures that each sensor is communicating to the correct `address <https://learn.adafruit.com/i2c-addresses/overview>`_. These are also used to define which variable you will be using to communicate with the sensor.

.. code-block:: cpp

   Adafruit_BME280 BME280;
   Adafruit_LTR390 LTR390 = Adafruit_LTR390();
   Adafruit_VEML7700 VEML7700 = Adafruit_VEML7700();
   ScioSense_ENS160 ENS160(ENS160_I2CADDR_0);
   SensirionI2CScd4x scd4x;

Define Data Types
-----------------

The next step is to define the data types of each variable. A data type is a way to standardize the formatting of a variable, such as if it is a text value, integer, boolean (True/False), or number with decimal places. Click `here <https://en.cppreference.com/w/cpp/language/types>`_ for the definitions of C++ fundamental types.

Below you can find the data types of the variables used in this example program. The version in the final code file is condensed to save on line-count.

.. code-block:: cpp

   float BME280_TEMP;      // Temperature
   float BME280_PRES;      // Pressure
   float BME280_HUMD;      // Humidity
   float BME280_HI;        // Heat-index
   float BME280_ALT;       // Barometric altitude
   float ENS160_AQI;       // Air Quality Index
   float ENS160_AQI_PREV;  // Previous AQI value
   float ENS160_TVOC;      // Total Volatile Organic Compounds
   float ENS160_eCO2;      // Calculated CO2 concentration
   float LTR390_UVI;       // Ultra-Violet Index
   float LTR390_RAW;       // Raw UV data
   float VEML7700_ALS;     // Ambient light data
   float VEML7700_WHITE;   // How much of the incoming light is white
   float VEML7700_LUX;     // Ambient light intensity
   float SCD40_CO2;        // Measured CO2 concentration
   float SCD40_TEMP;       // Temperature data from the CO2 sensor
   float SCD40_HUMD;       // Humidity data from the CO2 sensor
   
   int clock_timer;        // Time between data recordings
   int hh;                 // hours elapsed
   int mm;                 // minutes elapsed
   int ss;                 // seconds elapsed

   uint16_t SCD40_CO2_RAW; // Raw CO2 data

Setup Function
---------------

The next section is for the setup function. This is where all of the sensors are initialized and confirmed if they are connected or not. Each sensor has a slightly different initialization process, which is determined by the sensor libraries. Essentially, each sensor is checked to see if it is attached; if it is not, then it's status indicator is set to 0/False. Lastly, a header for all of the data parameters is printed to the serial monitor.

.. code-block:: cpp

   void setup() {
      Serial.begin(115200); // Set serial stream to 115200bits/s
      while(!Serial); // Wait until serial monitor is open

      //Initialize BME280 sensor
      if(!BME280.begin(0x76, &Wire)){
         Serial.print("\n\nBME280 not found");
      }

      //Initialize ENS160 sensor
      if(ENS160.begin()){
         if(!ENS160.setMode(ENS160_OPMODE_STD)){
            Serial.print("\n\nENS160 failed to init");
            ENS160_STS = 0;
         }
         delay(10);
         if(ENS160.available()){
            ENS160.measure(true);
            ENS160_AQI_PREV = ENS160.getAQI();
         }
      }
      else{
         Serial.print("\n\nENS160 not found");
         ENS160_STS = 0;
      }

      //Initialize LTR390 sensor
      if(!LTR390.begin()){
         Serial.print("\n\nLTR390 not found");
         LTR390_STS = 0;
      }
      else{
         LTR390.setMode(LTR390_MODE_UVS);
         LTR390.setGain(LTR390_GAIN_3);
         LTR390.setResolution(LTR390_RESOLUTION_16BIT);
         LTR390.setThresholds(100,1000);
         LTR390.configInterrupt(true, LTR390_MODE_UVS);
      }

      //Initialize VEML7700 sensor
      if(!VEML7700.begin()){
         Serial.print("\n\nVEML7700 not found");
         VEML7700_STS = 0;
      }
      else{
         VEML7700.setLowThreshold(10000);
         VEML7700.setHighThreshold(20000);
         VEML7700.interruptEnable(true);
      }

      //Initialize SCD40 sensor
      scd4x.begin(Wire);
      if(scd4x.stopPeriodicMeasurement() || scd4x.startPeriodicMeasurement()){
            Serial.print("\n\nSCD40 failed to respond");
            SCD40_STS = 0;
      }
      //Print data table header
      Serial.print("\n\n+==============================================================================+\n|  TIME  | TEMP | HUM |  HI  | PRES | ALT | CO2 | TVOC |  AQI  |  UVI  |  LUX  |\n|hh:mm:ss| (°C) | (%) | (°C) | hPa  | (m) |(ppm)|(ppb.)|(0-300)|(0-+11)|(k-lux)|\n+==============================================================================+");
      
      //Set timer variables to zero
      clock_timer = 0;
      hh = 0;
      mm = 0;
      ss = 0;
   }

Loop Function
-------------

The loop function is the main portion of the software where the data is collected and displayed. First, the variable for the delay_timer is set to be equal to the current processor clock time (in milliseconds). This is to help the code make sure it is refreshing at the correct rate.

.. code-block:: cpp
   
   int delay_timer = millis();

The next step is to read from all the individual sensors and preform any relevant calculations. Again, each sensor has it's own method to collect data.

BME280
^^^^^^

The Adafruit library for the BME280 makes it simple to collect data. It is a simple read function where you define the target variable and assign the data value to it.

.. code-block:: cpp

   BME280_TEMP = BME280.readTemperature();
   BME280_PRES = BME280.readPressure() / 100.0F;
   BME280_HUMD = BME280.readHumidity();
   BME280_ALT = BME280.readAltitude(SEALEVELPRESSURE_HPA);

Now, the data can be interpreted to get the desired weather parameters. With the BME280 weather sensor several parameters can be calculated. The ones featured in this program are `dew point <https://en.wikipedia.org/wiki/Dew_point>`_, `absolute humidity <https://en.wikipedia.org/wiki/Humidity>`_, and `heat index <https://en.wikipedia.org/wiki/Heat_index>`_. Only the calculation for heat index is active by default, but you can uncomment the dew point and absolute humidity calculations to include them. 

Heat index is calculated using `dry-bulb temperature <https://en.wikipedia.org/wiki/Dry-bulb_temperature>`_ and relative humidity. The formula used to calculate heat index was first derived in `The Assessment of Sultriness. Part I: A Temperature-Humidity Index Based on Human Physiology and Clothing Science <https://journals.ametsoc.org/view/journals/apme/18/7/1520-0450_1979_018_0861_taospi_2_0_co_2.xml>`_ by R.G. Steadman in 1979. His results were then interpreted by the National Weather Service in technical report `SR 90-23 <https://www.weather.gov/media/ffc/ta_htindx.PDF>`_ in 1990 to be approximated into an equation.

.. math:: HI = -42.379 + 2.04901523*T + 10.14333127*RH - 0.22375541*T*RH - 6.83783*10^(-3)*T^2 - 5.481717*10^(-2)*RH^2 + 1.22874*10^(-3)*T^2*RH + 8.5282*10*(-4)*T*RH^2 - 1.99*10^(-6)*T^2*RH^2
   :label: Heat-index equation
   :nowrap:

Where T is temperature in Fahrenheit and RH is relative humidity.

Because this is a regression fit, the equation has an error of ±1.3°F.

.. code-block:: cpp

   float h = (log10(BME280_HUMD)-2.0)/0.4343+(17.62*BME280_TEMP)/(243.12+BME280_TEMP);
  
   //Uncomment to calculate dew point and absolute humidity
   //float BME280_DEW_POINT = 243.12*h/(17.62-h); // Calculate dew point
   //float BME280_ABSOLUTE_HUMIDITY = 216.7*(BME280_HUMD/100.0*6.112*exp(17.62*BME280_TEMP/(243.12+BME280_TEMP))/(275.15+BME280_TEMP)); // Calculate absolute humidity

   float BME280_TEMP_F = (1.8*BME280_TEMP) + 32.0; // Convert Celsius to Fahrenheit

   //Calculate heat-index
   float BME280_HI_F = -42.379 + 2.04901523*BME280_TEMP_F + 10.14333127*BME280_HUMD - 0.22475541*BME280_TEMP_F*BME280_HUMD - 0.00683783*BME280_TEMP_F*BME280_TEMP_F - 0.05481717*BME280_HUMD*BME280_HUMD + 0.00122874*BME280_TEMP_F*BME280_TEMP_F*BME280_HUMD + 0.00085282*BME280_TEMP_F*BME280_HUMD*BME280_HUMD - 0.00000199*BME280_TEMP_F*BME280_TEMP_F*BME280_HUMD*BME280_HUMD; // Initial heat-index value

   if(BME280_HUMD < 13.0 && BME280_TEMP_F > 80.0 && BME280_TEMP_F < 112.0){ // If RH < 13% and 80 < T < 112
      BME280_HI_F = BME280_HI_F + (13.0 - BME280_HUMD)/4.0*sqrtf((17.0 - abs(BME280_TEMP_F - 95.0))/17);
   }
   else if(BME280_HUMD > 85 && BME280_TEMP_F > 80.0 && BME280_TEMP_F < 87.0){ // If RH > 85% and 80 < T < 87
      BME280_HI_F = BME280_HI_F + (BME280_HUMD - 85.0)/10*(87 - BME280_TEMP_F)/5;
   }
   else if(BME280_HI_F < 80.0){ // If HI < 80
      BME280_HI_F = 0.5 * (BME280_HI_F + 61.0 + 1.2*(BME280_HI_F - 68.0) + BME280_HUMD*0.094);
   }

   BME280_HI = (5.0/9.0)*(BME280_HI_F - 32.0); // Convert back to Celsius

ENS160
^^^^^^

The data collecting method for the ENS160 is very similar to the BME280. The parameters being collected are Air Quality Index (AQI) calculated from the German Federal Environmental Agency model, which is on a scale from 1 - 5, total volatile organic compounds (TVOC), and a calculated measurement of approximate Carbon-Dioxide concentration (eCO2).

.. code-block:: cpp

   ENS160.measure(true);
   ENS160_AQI = ENS160.getAQI();
   ENS160_TVOC = ENS160.getTVOC();
   ENS160_eCO2 = ENS160.geteCO2();

No further calculations need to be completed for this sensor.

LTR390
^^^^^^

Just like before, only the data needs to be pulled from the sensor with minimal calculations.

.. code-block:: cpp

   LTR390_RAW = LTR390.readUVS();
   LTR390_UVI = LTR390_RAW / 2300.00;

VEML7700
^^^^^^^^

.. code-block:: cpp

   VEML7700_LUX = VEML7700.readLux();

SCD40
^^^^^

.. code-block:: cpp

   bool isDataReady = false; // Reset Data-Ready flag
   if(scd4x.getDataReadyFlag(isDataReady)){
   }

   if(isDataReady){
      if(scd4x.readMeasurement(SCD40_CO2_RAW, SCD40_TEMP, SCD40_HUMD)){
      }
      else if(SCD40_CO2_RAW == 0){
      } 
      else{
         SCD40_CO2 = static_cast<float>(SCD40_CO2_RAW);
      }
   }
   else{
   }

Full Code
--------- 

Below is the full Sensor Test example sketch

.. code-block:: cpp

   //Import system libraries
   #include <Wire.h>

   //Import sensor libraries
   #include <Adafruit_BME280.h>
   #include <Adafruit_LTR390.h>
   #include <Adafruit_Sensor.h>
   #include <Adafruit_VEML7700.h>
   #include <ScioSense_ENS160.h>
   #include <SensirionI2CScd4x.h>

   #define SEALEVELPRESSURE_HPA (1013.25) //Define sea-level pressure as 1013.25hPa

   //Set sensor functions
   Adafruit_BME280 BME280;
   Adafruit_LTR390 LTR390 = Adafruit_LTR390();
   Adafruit_VEML7700 VEML7700 = Adafruit_VEML7700();
   ScioSense_ENS160 ENS160(ENS160_I2CADDR_0);
   SensirionI2CScd4x scd4x;

   //Define data types
   float BME280_TEMP, BME280_PRES, BME280_HUMD, BME280_HI, BME280_ALT, ENS160_AQI, ENS160_AQI_PREV, ENS160_TVOC, ENS160_eCO2, LTR390_UVI, LTR390_RAW, VEML7700_ALS, VEML7700_WHITE, VEML7700_LUX, SCD40_CO2, SCD40_TEMP, SCD40_HUMD;
   bool ENS160_STS = 1;
   bool LTR390_STS = 1;
   bool VEML7700_STS = 1;
   bool SCD40_STS = 1;
   int clock_timer, hh, mm, ss;
   uint16_t SCD40_CO2_RAW;

   float TVOC_CONCENTRATION_MIN = 5000;
   float TVOC_CONCENTRATION_MAX = 0;

   void setup() {
   Serial.begin(115200); // Set serial stream to 115200bits/s
   while(!Serial); // Wait until serial monitor is open

   //Initialize BME280 sensor
   if(!BME280.begin(0x76, &Wire)){
      Serial.print("\n\nBME280 not found");
   }

   //Initialize ENS160 sensor
   if(ENS160.begin()){
      if(!ENS160.setMode(ENS160_OPMODE_STD)){
         Serial.print("\n\nENS160 failed to init");
         ENS160_STS = 0;
      }
      delay(10);
      if(ENS160.available()){
         ENS160.measure(true);
         ENS160_AQI_PREV = ENS160.getAQI();
      }
   }
   else{
      Serial.print("\n\nENS160 not found");
      ENS160_STS = 0;
   }

   //Initialize LTR390 sensor
   if(!LTR390.begin()){
      Serial.print("\n\nLTR390 not found");
      LTR390_STS = 0;
   }
   else{
      LTR390.setMode(LTR390_MODE_UVS);
      LTR390.setGain(LTR390_GAIN_3);
      LTR390.setResolution(LTR390_RESOLUTION_16BIT);
      LTR390.setThresholds(100,1000);
      LTR390.configInterrupt(true, LTR390_MODE_UVS);
   }

   //Initialize VEML7700 sensor
   if(!VEML7700.begin()){
      Serial.print("\n\nVEML7700 not found");
      VEML7700_STS = 0;
   }
   else{
      VEML7700.setLowThreshold(10000);
      VEML7700.setHighThreshold(20000);
      VEML7700.interruptEnable(true);
   }

   //Initialize SCD40 sensor
   scd4x.begin(Wire);
   if(scd4x.stopPeriodicMeasurement() || scd4x.startPeriodicMeasurement()){
         Serial.print("\n\nSCD40 failed to respond");
         SCD40_STS = 0;
   }

   //Print data table header
   Serial.print("\n\n+==============================================================================+\n|  TIME  | TEMP | HUM |  HI  | PRES | ALT | CO2 | TVOC |  AQI  |  UVI  |  LUX  |\n|hh:mm:ss| (°C) | (%) | (°C) | hPa  | (m) |(ppm)|(ppb.)| (1-5) |(0-+11)|(k-lux)|\n+==============================================================================+");
   
   //Set timer variables to zero
   clock_timer = 0;
   hh = 0;
   mm = 0;
   ss = 0;
   }

   void loop() {
   int delay_timer = millis(); // Reset delay timer

   //Collect Data from BME280
   BME280_TEMP = BME280.readTemperature();
   BME280_PRES = BME280.readPressure() / 100.0F;
   BME280_HUMD = BME280.readHumidity();
   BME280_ALT = BME280.readAltitude(SEALEVELPRESSURE_HPA);

   float h = (log10(BME280_HUMD)-2.0)/0.4343+(17.62*BME280_TEMP)/(243.12+BME280_TEMP);
   
   //Uncomment to calculate dew point and absolute humidity
   //float BME280_DEW_POINT = 243.12*h/(17.62-h); // Calculate dew point
   //float BME280_ABSOLUTE_HUMIDITY = 216.7*(BME280_HUMD/100.0*6.112*exp(17.62*BME280_TEMP/(243.12+BME280_TEMP))/(275.15+BME280_TEMP)); // Calculate absolute humidity

   float BME280_TEMP_F = (1.8*BME280_TEMP) + 32.0; // Convert Celsius to Fahrenheit

   //Calculate heat-index
   float BME280_HI_F = -42.379 + 2.04901523*BME280_TEMP_F + 10.14333127*BME280_HUMD - 0.22475541*BME280_TEMP_F*BME280_HUMD - 0.00683783*BME280_TEMP_F*BME280_TEMP_F - 0.05481717*BME280_HUMD*BME280_HUMD + 0.00122874*BME280_TEMP_F*BME280_TEMP_F*BME280_HUMD + 0.00085282*BME280_TEMP_F*BME280_HUMD*BME280_HUMD - 0.00000199*BME280_TEMP_F*BME280_TEMP_F*BME280_HUMD*BME280_HUMD; // Initial heat-index value

   if(BME280_HUMD < 13.0 && BME280_TEMP_F > 80.0 && BME280_TEMP_F < 112.0){ // If RH < 13% and 80 < T < 112
      BME280_HI_F = BME280_HI_F + (13.0 - BME280_HUMD)/4.0*sqrtf((17.0 - abs(BME280_TEMP_F - 95.0))/17);
   }
   else if(BME280_HUMD > 85 && BME280_TEMP_F > 80.0 && BME280_TEMP_F < 87.0){ // If RH > 85% and 80 < T < 87
      BME280_HI_F = BME280_HI_F + (BME280_HUMD - 85.0)/10*(87 - BME280_TEMP_F)/5;
   }
   else if(BME280_HI_F < 80.0){ // If HI < 80
      BME280_HI_F = 0.5 * (BME280_HI_F + 61.0 + 1.2*(BME280_HI_F - 68.0) + BME280_HUMD*0.094);
   }

   BME280_HI = (5.0/9.0)*(BME280_HI_F - 32.0); // Convert back to Celsius
   
   // Retrieve data from ENS160 VOC sensor
   if(ENS160_STS && ENS160.available()){
      ENS160.measure(true);
      ENS160_AQI = ENS160.getAQI(); // Get air quality index
      ENS160_TVOC = ENS160.getTVOC(); // Get total volatile organic compound concentration in parts per billion
      ENS160_eCO2 = ENS160.geteCO2(); // Get eCO2 measurement, derived from TVOC
   }
   else{
      ENS160_AQI = 0;
      ENS160_TVOC = 0;
      ENS160_eCO2 = 0;
   }

   //Retrieve data from LTR390 UVA sensor
   if(LTR390_STS && LTR390.newDataAvailable()){
      LTR390_RAW = LTR390.readUVS();
      LTR390_UVI = LTR390_RAW / 2300.00; // Calculate UV-index from raw values
   }
   else{
      LTR390_UVI = 0;
   }

   if(VEML7700_STS){
      VEML7700_LUX = VEML7700.readLux(); // Retrieve data from VEML7700 ALS sensor
   }
   else{
      VEML7700_LUX = 0;
   }

   //Retrieve data from SCD40 CO2 sensors
   if(SCD40_STS){
      bool isDataReady = false; // Reset Data-Ready flag
      if(scd4x.getDataReadyFlag(isDataReady)){ // Check if there is data available to read
      }

      if(isDataReady){ // If data is ready to be read, read data
         if(scd4x.readMeasurement(SCD40_CO2_RAW, SCD40_TEMP, SCD40_HUMD)){
         }
         else if(SCD40_CO2_RAW == 0){ // If CO2 data is zero, keep data
         } 
         else{
            SCD40_CO2 = static_cast<float>(SCD40_CO2_RAW); // Cast CO2 unsigned 16bit-integer to type float
         }
      }
      else{ // If data is not ready, skip measurement
      }
   }
   else{
      SCD40_CO2 = 0;
   }
   
   //Clock timer
   ss = (millis() - clock_timer)/1000; // Set seconds to how much time has elapsed since first data read
   if(ss >= 60){ // If seconds is 60+, add 1 minutes and reset seconds variable
      clock_timer = millis();
      ss = ss - 60;
      mm = mm + 1;
      if(mm >= 60){ // If minutes is 60+, add 1 hours and reset minutes and seconds
         ss = ss - 60;
         mm = mm - 60;
         hh = hh + 1;
      }
   }

   char buffer[1024]; // Create 1024-bit buffer for data output
   sprintf(buffer, "\n|%02d:%02d:%02d| %5.2f|%5.2f| %5.2f|%6.1f|%5.1f| %4.0f| %5.0f|  %5.0f|  %5.2f|%7.2f|", hh, mm, ss, BME280_TEMP, BME280_HUMD, BME280_HI, BME280_PRES, BME280_ALT, SCD40_CO2, ENS160_TVOC, ENS160_AQI, LTR390_UVI, VEML7700_LUX);
   Serial.print(buffer); // Print buffer
   
   //Idle until it is time for next data read
   while(true){
      if(millis() - delay_timer >= 1000) break;
      delay(5);
      }
   }
0.

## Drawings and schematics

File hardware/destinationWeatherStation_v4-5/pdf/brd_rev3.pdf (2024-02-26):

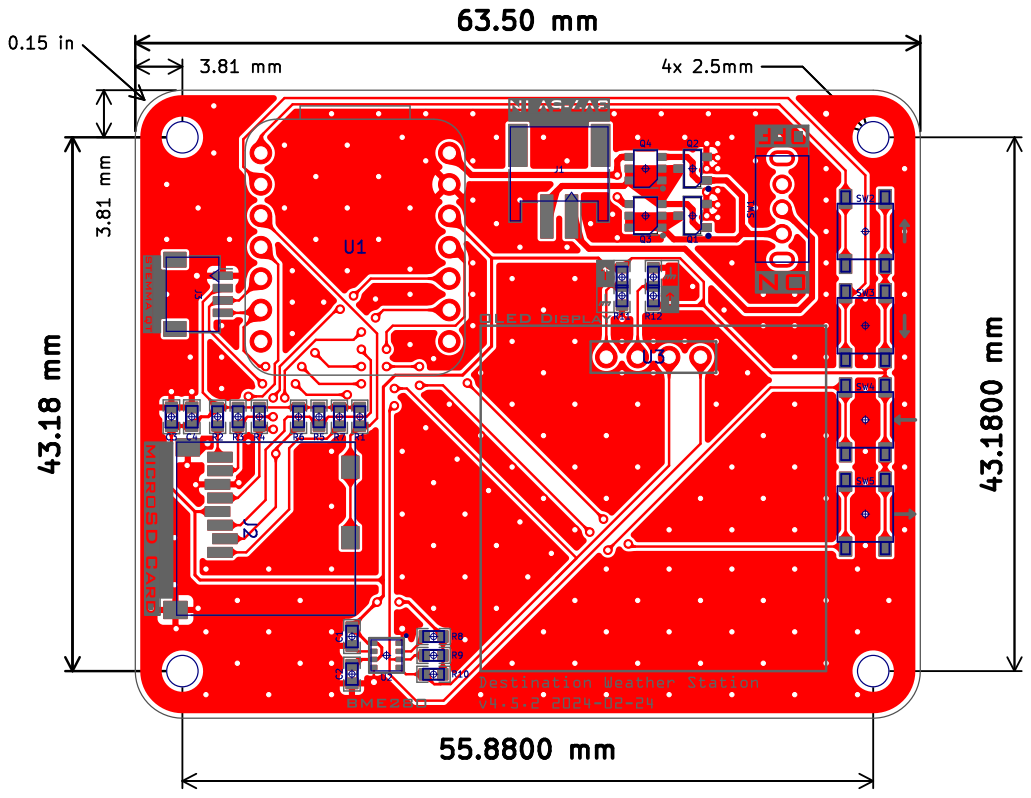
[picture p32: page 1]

Licensed under CERN OHLv2 - Permissive

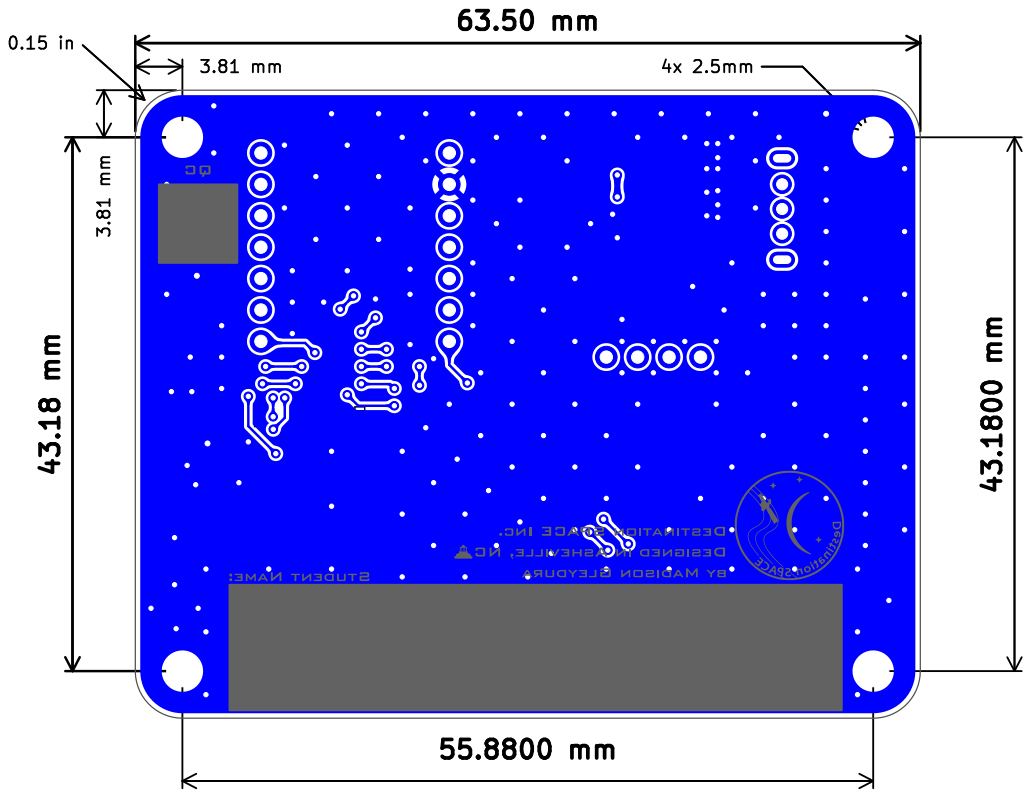
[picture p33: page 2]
Name:; Student QC; E Date: 2024-02-24; KiCad E.D.A.; kicad 7.0.11 Size: USLetter; Rev:03; Id: 1/1 Title:DestinationWeatherStationv4.5.2; File: destinationWeatherStation_r4-5.kicad_pcb; Sheet:; DestinationSPACEInc. Drawn By: Madison Gleydura Status FINAL VERSION © Destination; SPACE Inc. 2024

Licensed under CERN OHLv2 - Permissive

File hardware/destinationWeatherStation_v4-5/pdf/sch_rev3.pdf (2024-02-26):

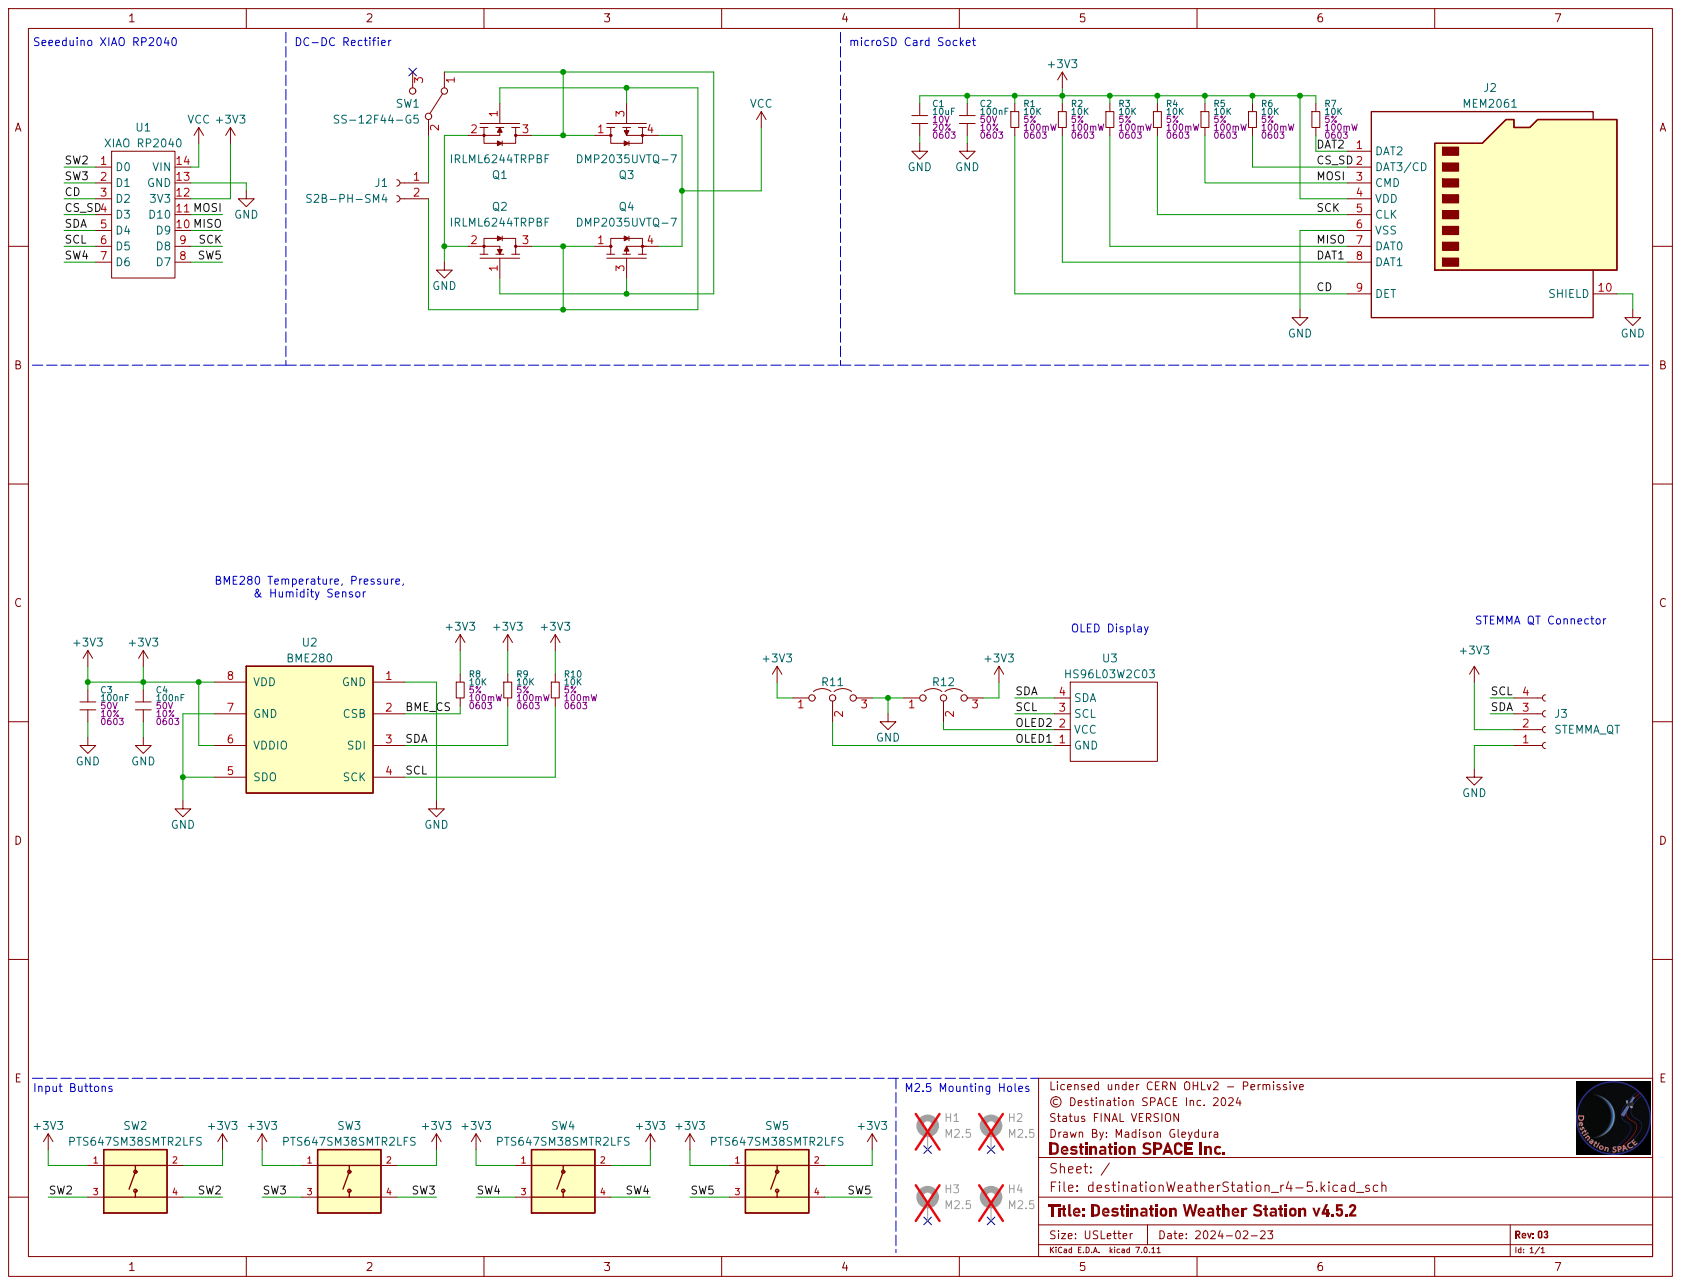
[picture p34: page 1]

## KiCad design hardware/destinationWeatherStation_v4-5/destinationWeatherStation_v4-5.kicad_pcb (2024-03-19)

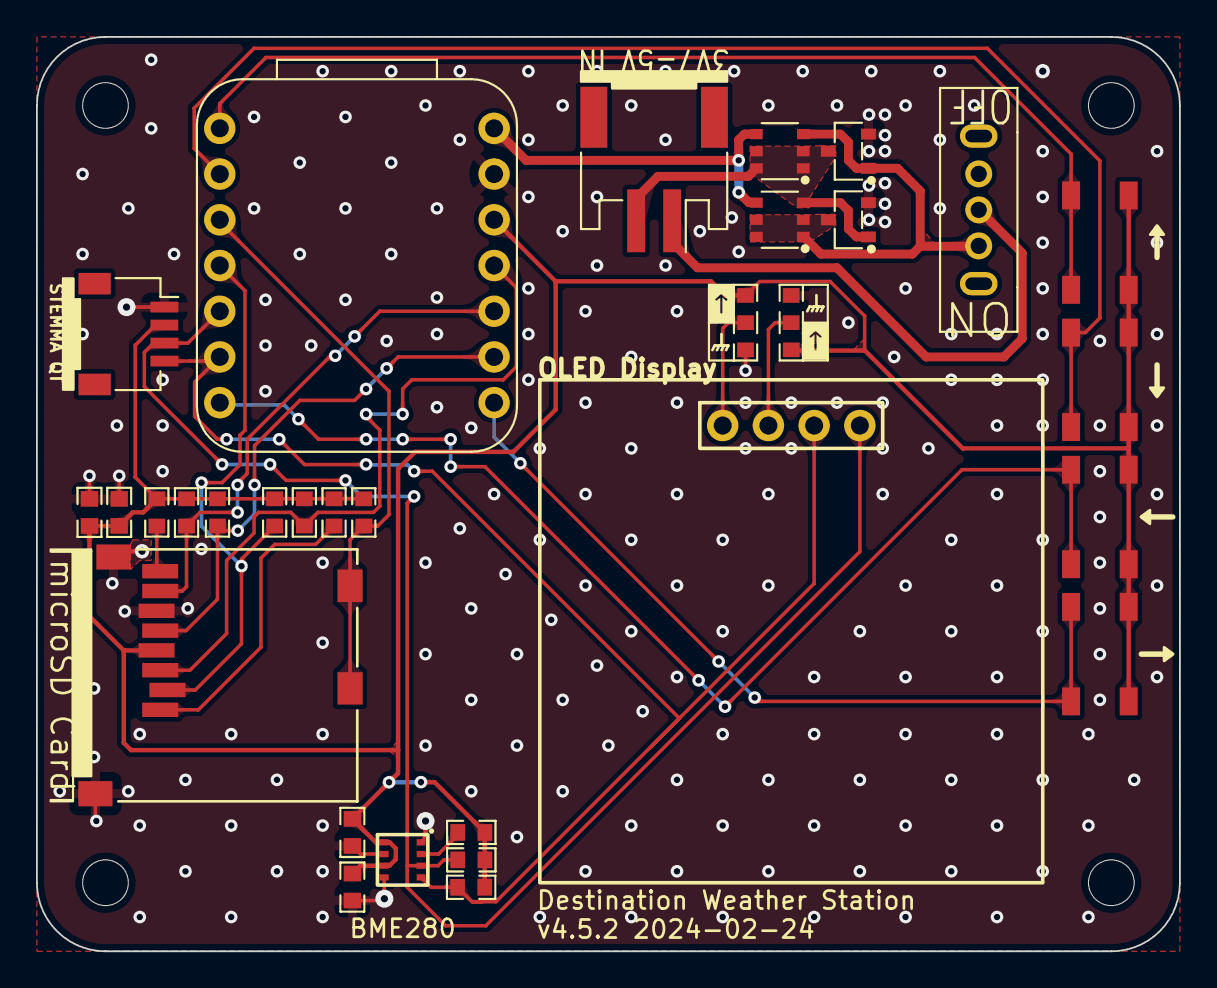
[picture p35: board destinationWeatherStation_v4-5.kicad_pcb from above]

Board: 2 copper layers, 63.5 x 50.8 mm, 35 parts (0 on the bottom side), 22 nets.

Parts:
C1: 10uF; CAPC160X80X88L35N
C2, C3, C4: 100nF; CAPC160X80X88L35N
H1, H2, H3, H4: M2.5; M2.54_NPTH
J1: S2B-PH-SM4; JST-PH-S2B-SM4-TB
J2: MEM2061
J3: STEMMA_QT; JST_SH_SM04B-SRSS-TB
Q1, Q2: IRLML6244TRPBF
Q3, Q4: DMP2035UVTQ-7; SOT23-6P95_280X100L40X37N
R1, R2, R3, R4, R5, R6, R7, R8, R9, R10: 10K; RESC160X80X55L30N
R11, R12: 0R; ResistorJumper-3
SW1: SS-12F44-G5; SS-12D07-VG_GA_PA
SW2, SW3, SW4, SW5: PTS647SM38SMTR2LFS; SW_4.5x4.5
U1: XIAO RP2040; QtPy
U2: BME280
U3: HS96L03W2C03

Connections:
+3V3: C1.1, C2.1, C3.1, C4.1, J2.4 (VDD), J3.2, R1.1, R2.1, R3.1, R4.1, R5.1, R6.1, R7.1, R8.1, R9.1, R10.1, R11.1 (A), R12.3 (B), SW2.1, SW2.2, SW3.1, SW3.2, SW4.1, SW4.2, SW5.1, SW5.2, U1.12 (3V3), U2.6 (VDDIO), U2.8 (VDD)
/BME_CS: R8.2, U2.2 (CSB)
/CD: J2.9 (DET), R1.2, U1.3 (D2)
/CS_SD: J2.2 (DAT3/CD), R6.2, U1.4 (D3)
/DAT1: J2.8 (DAT1), R2.2
/DAT2: J2.1 (DAT2), R7.2
/MISO: J2.7 (DAT0), R3.2, U1.10 (D9)
/MOSI: J2.3 (CMD), R5.2, U1.11 (D10)
/OLED1: R11.2 (C), U3.1 (GND)
/OLED2: R12.2 (C), U3.2 (VCC)
/SCK: J2.5 (CLK), R4.2, U1.9 (D8)
/SCL: J3.4, R10.2, U1.6 (D5), U2.4 (SCK), U3.3 (SCL)
/SDA: J3.3, R9.2, U1.5 (D4), U2.3 (SDI), U3.4 (SDA)
/SW2: SW2.3, SW2.4, U1.1 (D0)
/SW3: SW3.3, SW3.4, U1.2 (D1)
/SW4: SW4.3, SW4.4, U1.7 (D6)
/SW5: SW5.3, SW5.4, U1.8 (D7)
GND: C1.2, C2.2, C3.2, C4.2, J2.6 (VSS), J2.10 (SHIELD), J3.1, Q1.2, Q2.2, R11.3 (B), R12.1 (A), U1.13 (GND), U2.1 (GND), U2.5 (SDO), U2.7 (GND)
unnamed: J1.1, SW1.2 (B)
unnamed: J1.2, Q1.1, Q2.3, Q3.3, Q4.1, Q4.2, Q4.5, Q4.6
unnamed: Q1.3, Q2.1, Q3.1, Q3.2, Q3.5, Q3.6, Q4.3, SW1.1 (A)
VCC: Q3.4, Q4.4, U1.14 (VIN)

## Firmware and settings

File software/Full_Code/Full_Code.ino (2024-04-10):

/*******************************************************************************
DESTINATION WEATHER STATION V4.5 EXAMPLE - WEATHER STATION FULL EXAMPLE

This is an example sketch for the Destination Weather Station v4.5 remote
sensing platform to allow students to measure and record weather data.

modified 2024-03-13
by Madison Gleydura

MIT LICENSE AGREEMENT

Copyright © 2024 Destination SPACE Inc.

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
THE SOFTWARE IS PROVIDED “AS IS”, WITHOUT WARRANTY OF ANY KIND, EXPRESS OR
IMPLIED, INCLUDING BUT NOT LIMITED TO THE WARRANTIES OF MERCHANTABILITY, FITNESS
FOR A PARTICULAR PURPOSE AND NONINFRINGEMENT. IN NO EVENT SHALL THE AUTHORS OR
COPYRIGHT HOLDERS BE LIABLE FOR ANY CLAIM, DAMAGES OR OTHER LIABILITY, WHETHER
IN AN ACTION OF CONTRACT, TORT OR OTHERWISE, ARISING FROM, OUT OF OR IN
CONNECTION WITH THE SOFTWARE OR THE USE OR OTHER DEALINGS IN THE SOFTWARE.
*******************************************************************************/

//Import system libraries
#include <iostream>
#include <SPI.h>
#include <Wire.h>

//Import device libraries
#include <Adafruit_BME280.h>
#include <Adafruit_GFX.h>
#include <Adafruit_LTR390.h>
#include <Adafruit_NeoPixel.h>
#include <Adafruit_Sensor.h>
#include <Adafruit_SSD1306.h>
#include <Adafruit_VEML7700.h>
#include <ScioSense_ENS160.h>
#include <SdFat.h>
#include <SensirionI2CScd4x.h>

//Define hardware
#define BTN1 26
#define BTN2 27
#define BTN3 0
#define BTN4 1
#define CARD_DETECT 28
#define FILE_BASE_NAME "Log_"
#define RGB_R 17
#define RGB_G 16
#define RGB_B 25
#define NEOPIXEL_PWR 11
#define NEOPIXEL_PIN 12
#define NEOPIXEL_NUM 1
#define SCREEN_WIDTH 128
#define SCREEN_HEIGHT 64
#define OLED_RESET -1
#define SCREEN_ADDRESS 0x3C
#define SEALEVELPRESSURE_HPA (1013.25) //Define sea-level pressure as 1013.25hPa

//Set sensor functions
Adafruit_BME280 BME280;
Adafruit_LTR390 LTR390 = Adafruit_LTR390();
Adafruit_NeoPixel pixels(NEOPIXEL_NUM, NEOPIXEL_PIN, NEO_GRB + NEO_KHZ800);
Adafruit_SSD1306 display(SCREEN_WIDTH, SCREEN_HEIGHT, &Wire, OLED_RESET);
Adafruit_VEML7700 VEML7700 = Adafruit_VEML7700();
ScioSense_ENS160 ENS160(ENS160_I2CADDR_0);
SdFat SD;
SdFile file;
SensirionI2CScd4x scd4x;

//Define data types
float BME280_TEMP, BME280_PRES, BME280_HUMD, BME280_HI, BME280_ALT, ENS160_AQI, ENS160_AQI_PREV, ENS160_TVOC, ENS160_eCO2, LTR390_UVI, LTR390_RAW, VEML7700_ALS, VEML7700_WHITE, VEML7700_LUX, SCD40_CO2, SCD40_TEMP, SCD40_HUMD;
bool ENS160_STS = 1;
bool LTR390_STS = 1;
bool VEML7700_STS = 1;
bool SCD40_STS = 1;
int clock_timer, hh, mm, ss, BTN1_STATE, BTN2_STATE, BTN3_STATE, BTN4_STATE;
uint16_t SCD40_CO2_RAW;
const uint8_t SD_chipSelect = 29;
char fileName[13] = FILE_BASE_NAME "00.csv";
int menu = 1;
int i = 0;
bool logging = false;
int color_red = 0;
int color_grn = 0;
int color_blu = 0;
int delayAmount = 1000; //milliseconds

void setup() {
  Serial.begin(115200); // Set serial stream to 115200bits/s
  //while(!Serial); // Wait until serial monitor is open

  //Initialize LEDs
  pixels.begin();
  pinMode(NEOPIXEL_PWR, OUTPUT);
  digitalWrite(NEOPIXEL_PWR, HIGH);
  pinMode(RGB_R, OUTPUT);
  pinMode(RGB_G, OUTPUT);
  pinMode(RGB_B, OUTPUT);

  //Initialize OLED display
  if(!display.begin(SSD1306_SWITCHCAPVCC, SCREEN_ADDRESS)){
    Serial.print("\n\nOLED display not found");
    while(true){
      for(i=0;i<3;i++){
        pixels.setPixelColor(0, pixels.Color(0, 0, 80));
        pixels.show();
        delay(100);
        pixels.clear();
        delay(100);
      }
      i = 0;
      delay(500);
    }
  }
  else{
    display.setTextColor(WHITE);
    display.setTextSize(1);
    display.display();
    display.clearDisplay();
  }

  //Initialize BME280 sensor
  if(!BME280.begin(0x76, &Wire)){
    Serial.print("\n\nBME280 not found");
    display.clearDisplay();
    display.setCursor(0,0);
    display.print("BME280 not found");
    display.display();
    while(true){
    }
  }

  //Initialize ENS160 sensor
  if(ENS160.begin()){
    if(!ENS160.setMode(ENS160_OPMODE_STD)){
      Serial.print("\n\nENS160 failed to init");
      ENS160_STS = 0;
    }
    delay(10);
    if(ENS160.available()){
      ENS160.measure(true);
      ENS160_AQI_PREV = ENS160.getAQI();
    }
  }
  else{
    Serial.print("\n\nENS160 not found");
    ENS160_STS = 0;
  }

  //Initialize LTR390 sensor
  if(!LTR390.begin()){
    Serial.print("\n\nLTR390 not found");
    LTR390_STS = 0;
  }
  else{
    LTR390.setMode(LTR390_MODE_UVS);
    LTR390.setGain(LTR390_GAIN_3);
    LTR390.setResolution(LTR390_RESOLUTION_16BIT);
    LTR390.setThresholds(100,1000);
    LTR390.configInterrupt(true, LTR390_MODE_UVS);
  }

  //Initialize VEML7700 sensor
  if(!VEML7700.begin()){
    Serial.print("\n\nVEML7700 not found");
    VEML7700_STS = 0;
  }
  else{
    VEML7700.setLowThreshold(10000);
    VEML7700.setHighThreshold(20000);
    VEML7700.interruptEnable(true);
  }

  //Initialize SCD40 sensor
  scd4x.begin(Wire);
  if(scd4x.stopPeriodicMeasurement() || scd4x.startPeriodicMeasurement()){
    Serial.print("\n\nSCD40 failed to respond");
    SCD40_STS = 0;
  }

  //Initialize SD card
  pinMode(CARD_DETECT, INPUT); // Define card detect
  const uint8_t BASE_NAME_SIZE = sizeof(FILE_BASE_NAME) - 1;

  if(digitalRead(CARD_DETECT) == LOW){
    display.setCursor(0,0);
    display.print("insert microSD card");
    display.display();
    while(digitalRead(CARD_DETECT) == LOW){
      delay(500);
    }
  }
  else{
  }

  if(!SD.begin(SD_chipSelect, SD_SCK_MHZ(50))){
    display.setCursor(0,0);
    display.print("microSD card failure");
    display.display();
    while(true){
      if(SD.begin(SD_chipSelect, SD_SCK_MHZ(50))){
        break;
      }
      delay(100);
    }
    display.clearDisplay();
  }
  if(BASE_NAME_SIZE > 6){
    Serial.print("\n\nFile base name too long");
  }
  while(SD.exists(fileName)){
    if(fileName[BASE_NAME_SIZE + 1] != '9'){
      fileName[BASE_NAME_SIZE + 1]++;
    }
    else if(fileName[BASE_NAME_SIZE] != '9'){
      fileName[BASE_NAME_SIZE + 1] = '0';
      fileName[BASE_NAME_SIZE]++;
    }
    else{
      Serial.print("\n\nCan't create file name");
    }
  }
  if(!file.open(fileName, O_WRONLY | O_CREAT | O_EXCL)){
    Serial.print("\n\nError opening file");
  }
  file.println(F("Time (s),Temp (C),Hum (%),HI (C),PRES (hPa),ALT (m),CO2 (ppm),TVOC (ppb),AQI (1-5),UVI (0-11),LUX (k-lux)"));

  //Print data table header
  Serial.print("\n\n+==============================================================================+\n|  TIME  | TEMP | HUM |  HI  | PRES | ALT | CO2 | TVOC |  AQI  |  UVI  |  LUX  |\n|hh:mm:ss| (°C) | (%) | (°C) | hPa  | (m) |(ppm)|(ppb.)| (1-5) |(0-+11)|(k-lux)|\n+==============================================================================+");
  
  //Set timer variables to zero
  clock_timer = 0;
  hh = 0;
  mm = 0;
  ss = 0;
}

void setup1() {
  //Initialize buttons
  pinMode(BTN1, INPUT_PULLDOWN);
  pinMode(BTN2, INPUT_PULLDOWN);
  pinMode(BTN3, INPUT_PULLDOWN);
  pinMode(BTN4, INPUT_PULLDOWN);

  BTN1_STATE = 0;
  BTN2_STATE = 0;
  BTN3_STATE = 0;
  BTN4_STATE = 0;
}

void loop() {
  int delay_timer = millis(); // Reset delay timer
  pixels.setPixelColor(0, pixels.Color(0, 0, 80));
  setColor(color_grn, color_red, color_blu);
  pixels.show();

  //Collect Data from BME280
  BME280_TEMP = BME280.readTemperature();
  BME280_PRES = BME280.readPressure() / 100.0F;
  BME280_HUMD = BME280.readHumidity();
  BME280_ALT = BME280.readAltitude(SEALEVELPRESSURE_HPA);

  float h = (log10(BME280_HUMD)-2.0)/0.4343+(17.62*BME280_TEMP)/(243.12+BME280_TEMP);
  
  //Uncomment to calculate dew point and absolute humidity
  //float BME280_DEW_POINT = 243.12*h/(17.62-h); // Calculate dew point
  //float BME280_ABSOLUTE_HUMIDITY = 216.7*(BME280_HUMD/100.0*6.112*exp(17.62*BME280_TEMP/(243.12+BME280_TEMP))/(275.15+BME280_TEMP)); // Calculate absolute humidity

  //Calculate heat-index
  BME280_HI = 1.1*BME280_TEMP + 5*(0.047*BME280_HUMD - 7.1)/9; // Calculate initial heat-index value

  if((BME280_HI+BME280_TEMP)/2 >= 26.7){
    BME280_HI = -8.78469475556 + 1.61139411*BME280_TEMP + 2.33854883889*BME280_HUMD - 0.14611605*BME280_TEMP*BME280_HUMD + 0.012308094*BME280_TEMP*BME280_TEMP - 0.0164248277778*BME280_HUMD*BME280_HUMD + 0.002211732*BME280_TEMP*BME280_TEMP*BME280_HUMD + 0.00072546*BME280_TEMP*BME280_HUMD*BME280_HUMD - 0.000003582*BME280_TEMP*BME280_TEMP*BME280_HUMD*BME280_HUMD;
  }
  if(BME280_HUMD < 13 && BME280_TEMP > 26.7 && BME280_TEMP < 44.4){
    BME280_HI = BME280_HI + (5/36)*(BME280_HUMD-13)*sqrt((17-abs(1.8*BME280_TEMP-63))/17)-160/9;
  }
  else if(BME280_HUMD > 85 && BME280_TEMP > 26.7 && BME280_TEMP < 30.6){
    BME280_HI = BME280_HI + 5*(BME280_HUMD-85)*(55-1.8*BME280_TEMP)/450-160/9;
  }
  
  // Retrieve data from ENS160 VOC sensor
  if(ENS160_STS && ENS160.available()){
    ENS160.measure(true);
    ENS160_AQI = ENS160.getAQI(); // Get air quality index
    ENS160_TVOC = ENS160.getTVOC(); // Get total volatile organic compound concentration in parts per billion
    ENS160_eCO2 = ENS160.geteCO2(); // Get eCO2 measurement, derived from TVOC
  }
  else{
    ENS160_AQI = 0;
    ENS160_TVOC = 0;
    ENS160_eCO2 = 0;
  }

  //Retrieve data from LTR390 UVA sensor
  if(LTR390_STS && LTR390.newDataAvailable()){
    LTR390_RAW = LTR390.readUVS();
    LTR390_UVI = LTR390_RAW / 2300.00; // Calculate UV-index from raw values
  }
  else{
    LTR390_UVI = 0;
  }

  //Retrieve data from VEML7700 ambient light sensor
  if(VEML7700_STS){
    VEML7700_LUX = VEML7700.readLux(); // Retrieve data from VEML7700 ALS sensor
  }
  else{
    VEML7700_LUX = 0;
  }

  //Retrieve data from SCD40 CO2 sensor
  if(SCD40_STS){
    bool isDataReady = false; // Reset Data-Ready flag
    if(scd4x.getDataReadyFlag(isDataReady)){ // Check if there is data available to read
    }

    if(isDataReady){ // If data is ready to be read, read data
      if(scd4x.readMeasurement(SCD40_CO2_RAW, SCD40_TEMP, SCD40_HUMD)){
      }
      else if(SCD40_CO2_RAW == 0){ // If CO2 data is zero, keep data
      } 
      else{
        SCD40_CO2 = static_cast<float>(SCD40_CO2_RAW); // Cast CO2 unsigned 16bit-integer to type float
      }
    }
    else{ // If data is not ready, skip measurement
    }
  }
  else{
    SCD40_CO2 = 0;
  }
  
  //Clock timer
  ss = (millis() - clock_timer)/1000; // Set seconds to how much time has elapsed since first data read
  if(ss >= 60){ // If seconds is 60+, add 1 minutes and reset seconds variable
    clock_timer = millis();
    ss = ss - 60;
    mm = mm + 1;
    if(mm >= 60){ // If minutes is 60+, add 1 hours and reset minutes and seconds
      ss = ss - 60;
      mm = mm - 60;
      hh = hh + 1;
    }
  }

  //Print data to serial monitor
  char buffer[1024]; // Create 1024bit buffer for data output
  sprintf(buffer, "\n|%02d:%02d:%02d| %5.2f|%5.2f| %5.2f|%6.1f|%5.1f| %4.0f| %5.0f|  %5.0f|  %5.2f|%7.2f|", hh, mm, ss, BME280_TEMP, BME280_HUMD, BME280_HI, BME280_PRES, BME280_ALT, SCD40_CO2, ENS160_TVOC, ENS160_AQI, LTR390_UVI, VEML7700_LUX);
  Serial.print(buffer); // Print buffer

  //Print data to OLED display
  switch(menu){
    case 1: // Weather menu
      display.clearDisplay();
      if(logging){
        display.setCursor(110,0); display.setTextColor(SSD1306_WHITE); display.print("O");
      }
      else{
        display.setCursor(110,0); display.setTextColor(SSD1306_BLACK); display.print("O"); display.setTextColor(SSD1306_WHITE);
      }
      display.setCursor(0,0);   display.print("Weather Menu");
      display.setCursor(0,20);  display.print("Temperature: ");  display.print(BME280_TEMP, 2);  display.print("C");
      display.setCursor(0,30);  display.print("Pressure: ");     display.print(BME280_PRES, 1);  display.print("hPa");
      display.setCursor(0,40);  display.print("Humidity: ");     display.print(BME280_HUMD, 2);  display.print("%");
      display.setCursor(0,50);  display.print("Heat Index: ");   display.print(BME280_HI, 2);    display.print("C");
      display.display();
      break;
    
    case 2: //Air quality menu
      display.clearDisplay();
      if(logging){
        display.setCursor(110,0); display.setTextColor(SSD1306_WHITE); display.print("O");
      }
      else{
        display.setCursor(110,0); display.setTextColor(SSD1306_BLACK); display.print("O"); display.setTextColor(SSD1306_WHITE);
      }
      display.setCursor(0,0);   display.print("Air Quality Menu");
      display.setCursor(0,20);  display.print("CO2: ");          display.print(SCD40_CO2, 0);    display.print("ppm");
      display.setCursor(0,30);  display.print("TVOC: ");         display.print(ENS160_TVOC, 0);  display.print("ppb");
      display.setCursor(0,40);  display.print("AQI: ");         display.print(ENS160_AQI, 0);
      display.display();
      break;

    case 3: //Light menu
      display.clearDisplay();
      if(logging){
        display.setCursor(110,0); display.setTextColor(SSD1306_WHITE); display.print("O");
      }
      else{
        display.setCursor(110,0); display.setTextColor(SSD1306_BLACK); display.print("O"); display.setTextColor(SSD1306_WHITE);
      }
      display.setCursor(0,0);   display.print("Light Menu");
      display.setCursor(0,20);  display.print("UVI: ");          display.print(LTR390_UVI, 2);
      display.setCursor(0,30);  display.print("ALS: ");         display.print(VEML7700_LUX, 2);  display.print("Lux");
      display.display();
      break;

    case 4:
      display.clearDisplay();
      if(logging){
        display.setCursor(110,0); display.setTextColor(SSD1306_WHITE); display.print("O");
      }
      else{
        display.setCursor(110,0); display.setTextColor(SSD1306_BLACK); display.print("O"); display.setTextColor(SSD1306_WHITE);
      }
      display.setCursor(0,0); display.print("SD Config...");
      int16_t x1, y1;
      uint16_t w, h;
      display.getTextBounds("Start Recording...", 2, 20, &x1, &y1, &w,&h);
      display.fillRect(x1-2,y1-2,w+4,h+4, SSD1306_WHITE);
      display.setTextColor(SSD1306_BLACK); display.setCursor(2,20); display.print("Start Recording...");
      display.setTextColor(SSD1306_WHITE); display.setCursor(2,30); display.print("Pause Recording...");
      display.setTextColor(SSD1306_WHITE); display.setCursor(2,40); display.print("Exit Settings");
      display.display();
      break;
    
    case 5:
      display.clearDisplay();
      if(logging){
        display.setCursor(110,0); display.setTextColor(SSD1306_WHITE); display.print("O");
      }
      else{
        display.setCursor(110,0); display.setTextColor(SSD1306_BLACK); display.print("O"); display.setTextColor(SSD1306_WHITE);
      }
      display.setCursor(0,0); display.print("SD Config...");
      x1, y1;
      w, h;
      display.getTextBounds("Pause Recording...", 2, 30, &x1, &y1, &w,&h);
      display.fillRect(x1-2,y1-2,w+4,h+4, SSD1306_WHITE);
      display.setTextColor(SSD1306_WHITE); display.setCursor(2,20); display.print("Start Recording...");
      display.setTextColor(SSD1306_BLACK); display.setCursor(2,30); display.print("Pause Recording...");
      display.setTextColor(SSD1306_WHITE); display.setCursor(2,40); display.print("Exit Settings");
      display.display();
      break;

    case 6:
      display.clearDisplay();
      if(logging){
        display.setCursor(110,0); display.setTextColor(SSD1306_WHITE); display.print("O");
      }
      else{
        display.setCursor(110,0); display.setTextColor(SSD1306_BLACK); display.print("O"); display.setTextColor(SSD1306_WHITE);
      }
      display.setCursor(0,0); display.print("SD Config...");
      x1, y1;
      w, h;
      display.getTextBounds("Exit Settings", 2, 40, &x1, &y1, &w,&h);
      display.fillRect(x1-2,y1-2,w+4,h+4, SSD1306_WHITE);
      display.setTextColor(SSD1306_WHITE); display.setCursor(2,20); display.print("Start Recording...");
      display.setTextColor(SSD1306_WHITE); display.setCursor(2,30); display.print("Pause Recording...");
      display.setTextColor(SSD1306_BLACK); display.setCursor(2,40); display.print("Exit Settings");
      display.setTextColor(SSD1306_WHITE);
      display.display();
      break;

    case 7:
      display.clearDisplay();
      if(logging){
        display.setCursor(110,0); display.setTextColor(SSD1306_WHITE); display.print("O");
      }
      else{
        display.setCursor(110,0); display.setTextColor(SSD1306_BLACK); display.print("O"); display.setTextColor(SSD1306_WHITE);
      }
      display.setCursor(0,0); display.print("Destination WX Stn");
      display.setCursor(2,20); display.print("gitlab.com/");
      display.setCursor(2,30); display.print("Destination-SPACE");
      display.setCursor(2,40); display.print("ds-weather-station-v4.5");
      display.display();
      break;

    default:
      break;
  }

  //Write data to the SD card
  if(logging){
    char FILE_BUFFER[1024];
    sprintf(FILE_BUFFER, "%02d:%02d:%02d,%5.2f,%5.2f,%5.2f,%6.1f,%5.1f,%4.0f,%5.0f,%5.0f,%5.2f,%7.2f", hh, mm, ss, BME280_TEMP, BME280_HUMD, BME280_HI, BME280_PRES, BME280_ALT, SCD40_CO2, ENS160_TVOC, ENS160_AQI, LTR390_UVI, VEML7700_LUX);
    delay(50);
    file.println(FILE_BUFFER);
    if(!file.sync() || file.getWriteError()){
      Serial.print("\n\nWrite Error");
    }
  }
  pixels.clear();
  pixels.show();
  setColor(0, 0, 0);
  //Idle until it is time for next data read
  while(true){
    if(millis() - delay_timer >= delayAmount) break;
    delay(5);
  }
}

//Button menu-input loop
void loop1() {
  if(digitalRead(BTN1)){
    delay(100);
    if(digitalRead(BTN1)){
      display.clearDisplay();
      i = 0;
      menu = 4;
      logging = true;
      color_red = 255;
      color_grn = 0;
      color_blu = 0;
      delay(1);
      while(i == 0){
        if(digitalRead(BTN1)){
          delay(100);
          if(digitalRead(BTN1)){
            logging = true;
            color_red = 255;
            color_grn = 0;
            color_blu = 0;
            menu = menu - 1;
            if(menu < 4){
              menu = 6;
            }
          }
        }
        if(digitalRead(BTN2)){
          delay(100);
          if(digitalRead(BTN2)){
            logging = false;
            color_red = 0;
            color_grn = 0;
            color_blu = 0;
            menu = menu + 1;
            if(menu > 6){
              menu = 4;
            }
          }
        }
        if(digitalRead(BTN4)){
          delay(100);
          if(digitalRead(BTN4)){
            if(menu = 4){
              //logging = true;
            }
            else if(menu = 5){
              //logging = false;
            }
            else{
            }
            menu = 1;
            i = 1;
          }
        }
      }
    }
    delay(100);
  }

  if(digitalRead(BTN2)){
    delay(100);
    if(digitalRead(BTN2)){
      display.clearDisplay();
      display.setCursor(0,0);
      display.print("Loading...");
      display.display();
      menu = 7;
      while(digitalRead(BTN2)){
        delay(100);
      }
      menu = 1;
    }
    delay(100);
  }

  if(digitalRead(BTN3)){
    delay(100);
    if(digitalRead(BTN3)){
      display.clearDisplay();
      display.setCursor(0,0);
      display.print("Loading...");
      display.display();
      menu = menu - 1;
      if(menu < 1){
        menu = 3;
      }
    }
    delay(100);
  }

  if(digitalRead(BTN4)){
    delay(100);
    if(digitalRead(BTN4)){
      display.clearDisplay();
      display.setCursor(0,0);
      display.print("Loading...");
      display.display();
      menu = menu + 1;
      if(menu > 3){
        menu = 1;
      }
    }
    delay(100);
  }
}

void setColor(int VAL_GRN, int VAL_RED, int VAL_BLU){
  analogWrite(RGB_R, 255 - VAL_RED);
  analogWrite(RGB_G, 255 - VAL_GRN);
  analogWrite(RGB_B, 255 - VAL_BLU);
}

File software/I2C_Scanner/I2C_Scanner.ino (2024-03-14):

// --------------------------------------
// i2c_scanner
//
// Modified from https://playground.arduino.cc/Main/I2cScanner/
// --------------------------------------

#include <Wire.h> // Import I2C Wire library

// Set I2C bus to use: Wire, Wire1, etc.
#define WIRE Wire

void setup() {
  WIRE.begin();

  Serial.begin(115200);
  while (!Serial)
     delay(10);
  Serial.println("\nI2C Scanner");
}


void loop() {
  byte error, address;
  int nDevices;

  Serial.println("Scanning...");

  nDevices = 0;
  for(address = 1; address < 127; address++ ) 
  {
    // The i2c_scanner uses the return value of
    // the Write.endTransmisstion to see if
    // a device did acknowledge to the address.
    WIRE.beginTransmission(address);
    error = WIRE.endTransmission();

    if (error == 0)
    {
      Serial.print("I2C device found at address 0x");
      if (address<16) 
        Serial.print("0");
      Serial.print(address,HEX);
      Serial.println("  !");

      nDevices++;
    }
    else if (error==4) 
    {
      Serial.print("Unknown error at address 0x");
      if (address<16) 
        Serial.print("0");
      Serial.println(address,HEX);
    }    
  }
  if (nDevices == 0)
    Serial.println("No I2C devices found\n");
  else
    Serial.println("done\n");

  delay(5000); // wait 5 seconds for next scan
}

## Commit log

2024-01-15 added hardware files
    [BME280.STEP, C0603C104K5RACTU.stp, CRCW0603.STEP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]
2024-01-15 added BOM
    [destinationWeatherStation_r4-5-DigiKey.xlsx, destinationWeatherStation_r4-5-LCSC.xlsx, destinationWeatherStation_r4-5.csv]
2024-01-15 deleted old gerbers
    [destinationWeatherStation_r4-5-B_Cu.gbr, destinationWeatherStation_r4-5-B_Mask.gbr, destinationWeatherStation_r4-5-B_Paste.gbr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]
2024-02-12 finalized PCB CAD
    [SS-12F44.stp, SS12D07VG4.STEP, destinationWeatherStation_r4-5.kicad_pcb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]
2024-02-13 added html files
    [weather-station-configuration.rst.txt]
2024-02-16 file touchups
    [destinationWeatherStation_r4-5-B_Cu.gbr, destinationWeatherStation_r4-5-B_Fab.gbr, destinationWeatherStation_r4-5-B_Mask.gbr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]
2024-02-17 kicad backups
2024-02-20 blender stuff
    [destinationWeatherStation_r4-5.blend, destinationWeatherStation_r4-5.kicad_pcb, destinationWeatherStation_r4.step]
2024-02-24 3d pdf stuff and board fixes
    [destinationWeatherStation_r4-5-B_Cu.gbr, destinationWeatherStation_r4-5-B_Fab.gbr, destinationWeatherStation_r4-5-B_Mask.gbr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]
2024-02-24 final CAD changes
    [destinationWeatherStation_r4-5-B_Cu.gbr, destinationWeatherStation_r4-5-B_Fab.gbr, destinationWeatherStation_r4-5-B_Mask.gbr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]
2024-02-28 assembly instructions
2024-03-04 fixed repaced wx stn code with demo, and modeified demo code
    [Demo.ino]
2024-03-04 test jig code
    [destinationWeatherStation_r4-5.kicad_sch]
2024-03-07 blender renders
    [destinationWeatherStation_r4-5.kicad_pcb]
2024-03-09 added assembly images
2024-03-09 install arduino ide changes
2024-03-10 sensor pages
2024-03-11 deleted temp files. fixed .gitignore
    [Blink.ino, Full_Code.ino]
2024-03-11 added details about UV sensor
2024-03-11 fixed resistor quantity
    [destinationWeatherStation_r4-5.csv]
2024-03-13 removed calibration file
2024-03-13 reordered sensors
2024-03-13 removed i2c scanner page
2024-03-19 changed file names
    [BME280.STEP, C0603C104K5RACTU.stp, CRCW0603.STEP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]
2024-03-19 balloon mount assembly and stl
    [94180A321_Tapered Heat-Set Inserts for Plastic.STEP, 94180A321_Tapered Heat-Set Inserts for Plastic.ipt, ASSEMBLY.ipt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]
2024-03-21 created sensor activity pages
2024-03-26 sensor test program overview
2024-04-02 added button menu instructions
2024-04-02 fixed code to work with or without expansion sensors
    [Demo.ino, Full_Code.ino, Sensor_Test.ino]
2024-04-02 fixed heat-index formula
